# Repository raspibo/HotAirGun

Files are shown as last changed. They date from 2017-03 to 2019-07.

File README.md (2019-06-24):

HotAirGun
===================== 
Hot Air Solder station project
3D models for case

Project preview
=====================

<table>
<tr>
<td>
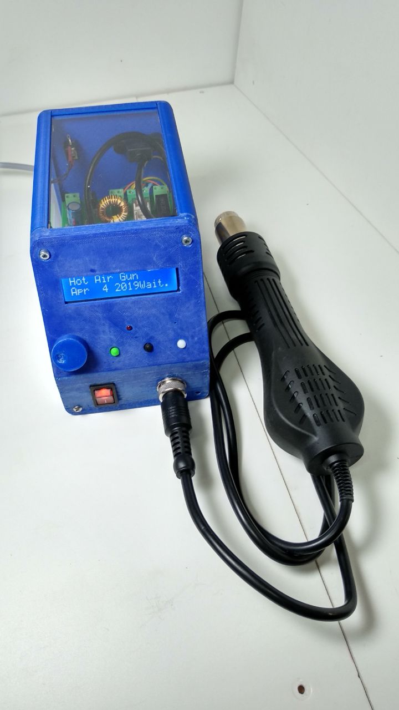
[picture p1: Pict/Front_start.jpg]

</td><td>
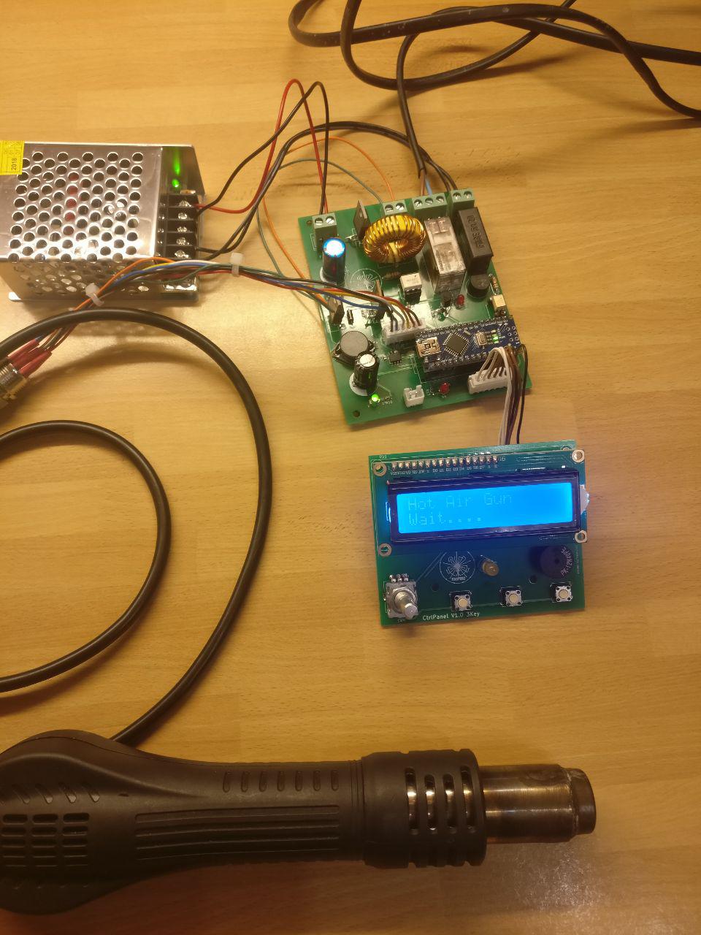
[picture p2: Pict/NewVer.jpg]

</td><td>
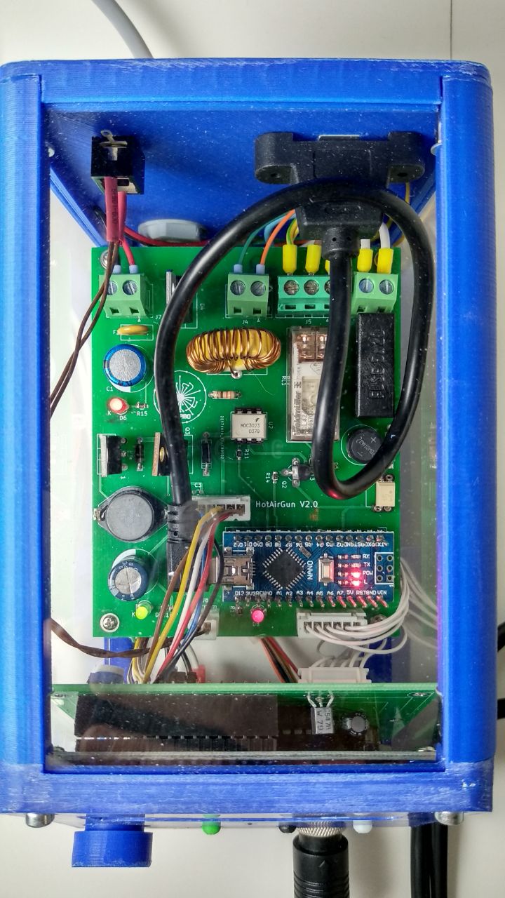
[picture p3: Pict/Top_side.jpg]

</td>
</tr>
<tr>
<td>
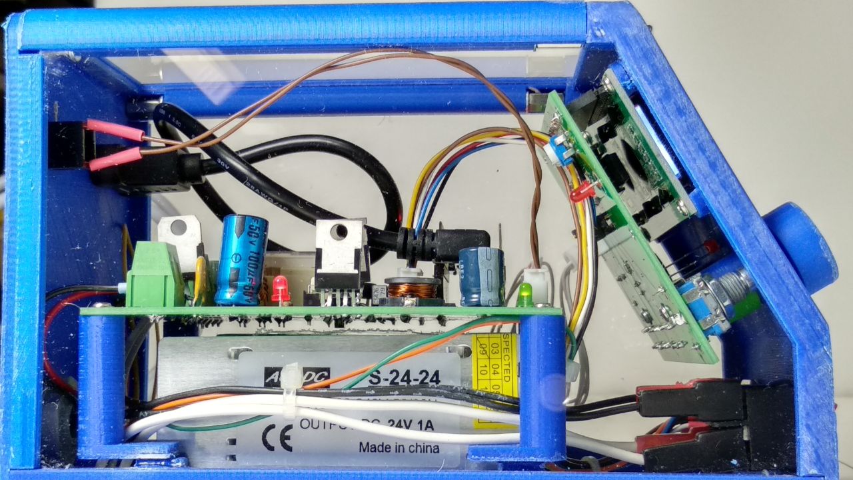
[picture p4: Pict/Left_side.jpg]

</td><td>
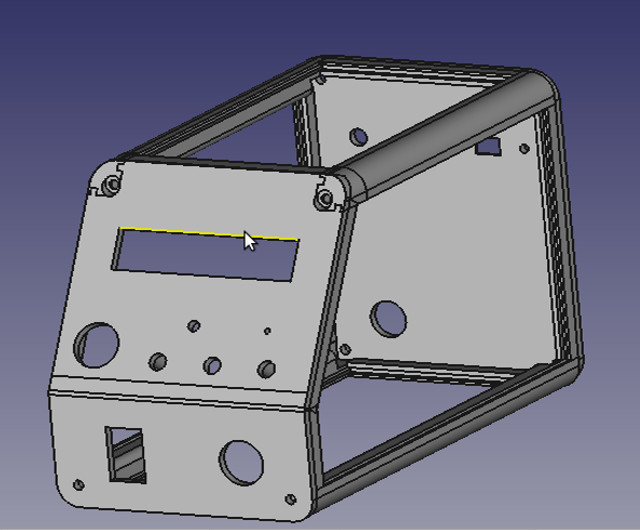
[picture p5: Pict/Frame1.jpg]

</td><td>
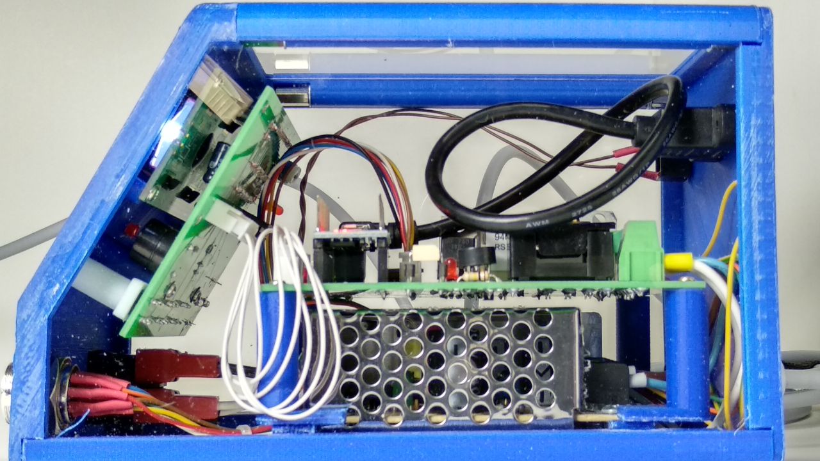
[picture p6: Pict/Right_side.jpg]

</td>
</tr>
</table>

License and copyright
=====================

Copyright 2017-2018 sandroxGH infomsystemsrl@gmail.com, RaspiBO info@raspibo.org

Licensed under the Apache License, Version 2.0 (the "License"); you may not use this file except in compliance with the License. You may obtain a copy of the License at http://www.apache.org/licenses/LICENSE-2.0

Unless required by applicable law or agreed to in writing, software distributed under the License is distributed on an "AS IS" BASIS, WITHOUT WARRANTIES OR CONDITIONS OF ANY KIND, either express or implied. See the License for the specific language governing permissions and limitations under the License.

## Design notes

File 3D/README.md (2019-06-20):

Mounting note for the HAG housing frame

===================== 

To build the frame I've use ABS more flexible and a good meccanical resistance than PLA, but finally all material are good. 
The model is slice at 0,15mm a good balnce between definistion and strenght.
For the column mounting have to add a threaded bar , 2 washer  and 2 spacer of 10mm all in M3 size. The upper column use e thread bar of 110mm and the lowe 158 mm, to asembly use threadlocker.

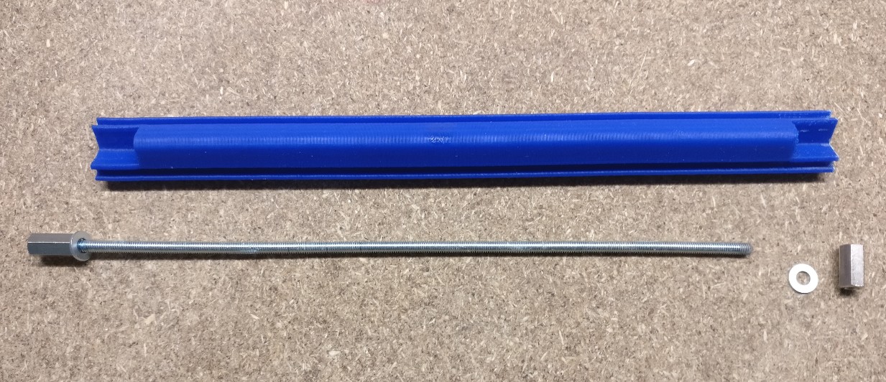
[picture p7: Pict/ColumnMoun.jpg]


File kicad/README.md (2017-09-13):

# Avvertenza sul caricamento dei simboli
All'apertura dello schema kicad può richiedere di sostituire i simboli dei componenti come se si riferissero a librerie obsolete.

E' consigliabile annullare l'operazione in modo che venga caricato il simbolo presente nel file cache delle librerie.

Schema preview
=====================


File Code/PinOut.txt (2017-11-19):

1	D1/TX	Connesisone seriale 
2	D0/RX	Connesisone seriale
3	RESET
4	GND
5	D2*		Fase 0
6	D3		MCP_INT
7	D4		
8	D5*		MAX6675_SO
9	D6* 	MAX6675_CS
10	D7		MAX6675_CLK
11	D8		Relè sic 220V
12	D9* 	Triac
13	D10*		
14	D11* 	Mosfet "Fan"
15	D12  	
16	D13		LedR
17	3V3		
18	AREF
19	A7		
20	A6		
21	A5		LCD I2c
22	A4		LCD I2c
23	A3		
24	A2		
25	A1		
26	A0		
27	+5V
28	RESET
29	GND
30	VIN

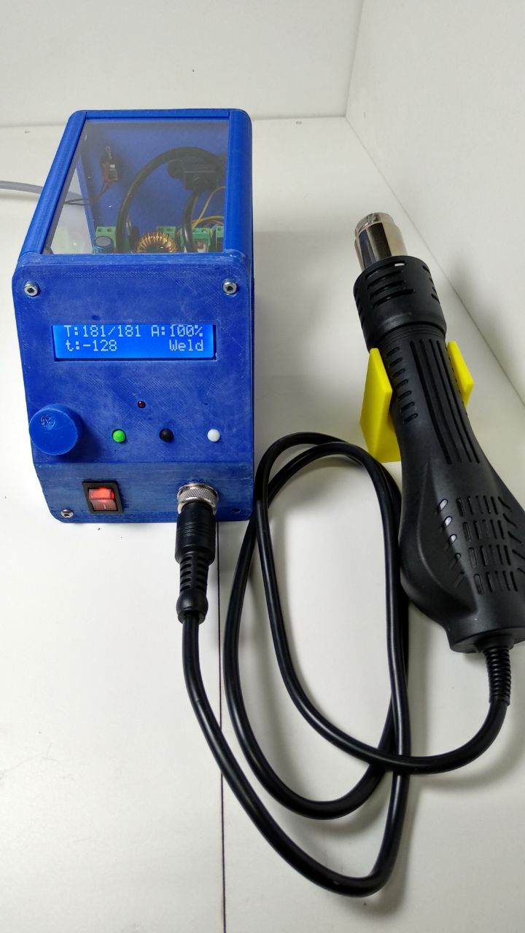
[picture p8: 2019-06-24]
Pict/Front_weld.jpg

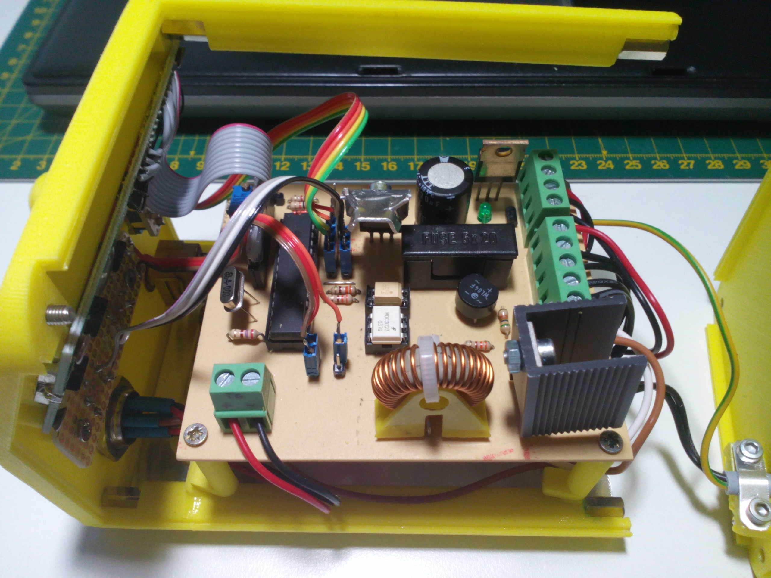
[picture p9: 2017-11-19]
Pict/HAG.jpg

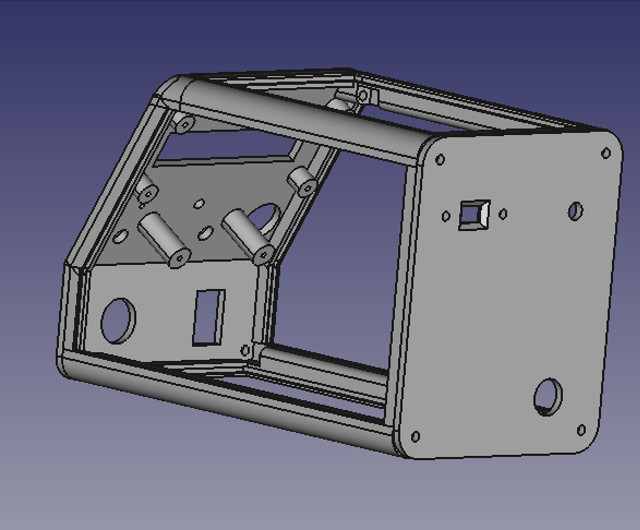
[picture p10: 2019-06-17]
Pict/Frame2.jpg

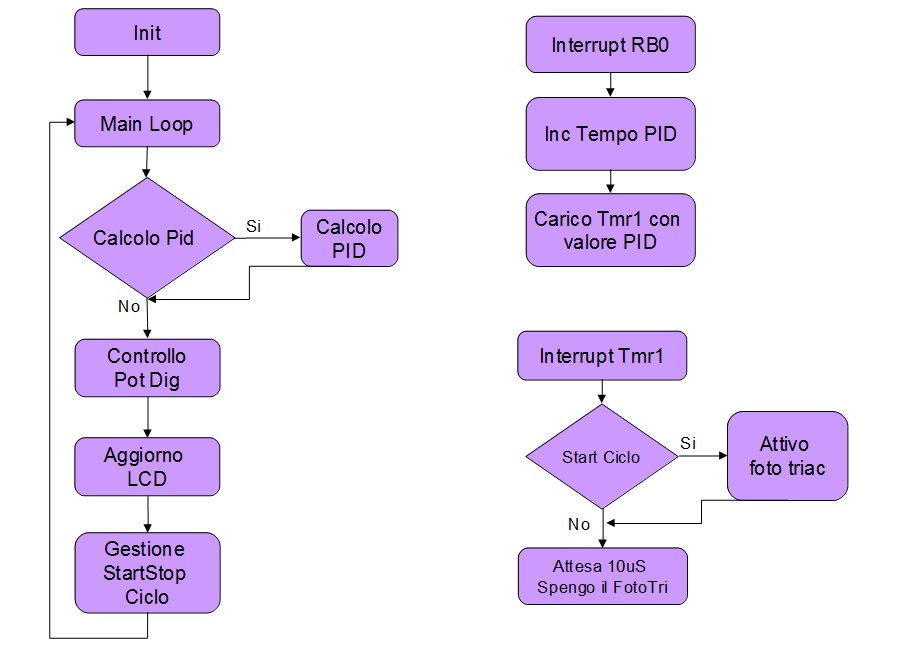
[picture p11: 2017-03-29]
Pict/Flow1.jpg

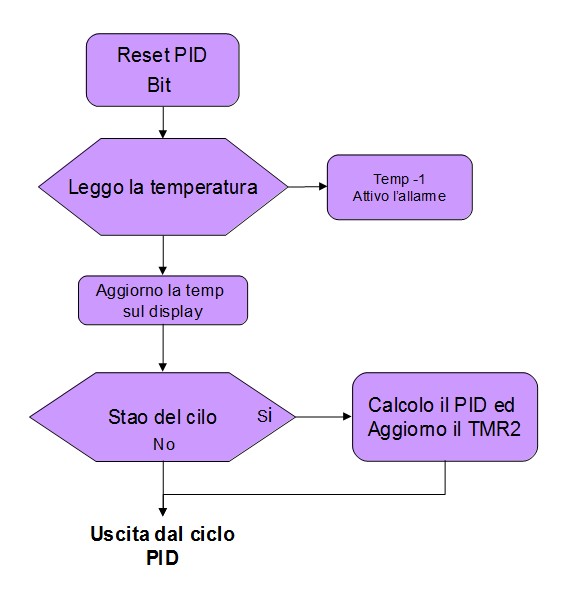
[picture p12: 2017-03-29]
Pict/Flow2.jpg

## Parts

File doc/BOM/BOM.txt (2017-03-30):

#Lista materiali per la sperimentazione iniziale

Quantita   Materiale
1          Pistola saldatore ad aria calda          
1          Arduino Nano
1          Display LCD 16x2
1          interfaccia per display I2c
1          Alimentatore switching 12V 2A    ( 24V 1A)
1          Encoder con click "Rotella multifunzione"
2          Pulsanti No
3          Led Verdi 3mm
1          Led Rosso 3mm
QB         Resistenze
1          MAX6675
1          IRF740
1          Porta fusibile 5x20
1          Ponte raddrizzatore
1          Fotocaccopiatore MOC3032
1          Fotocaccopiatore TLP672
1          Diodo BA159
1          Induttanza 10mH 1A
2          Condensatori ceramici 10pF

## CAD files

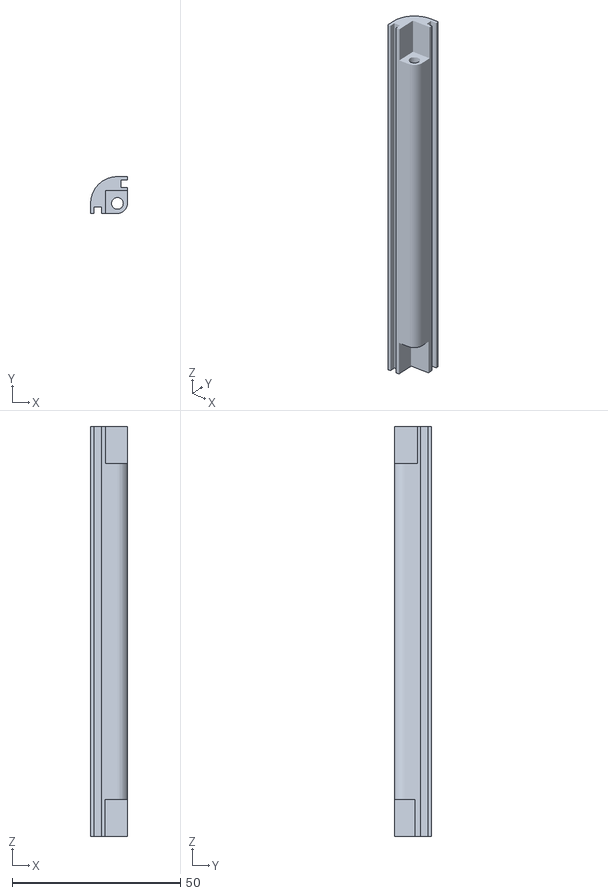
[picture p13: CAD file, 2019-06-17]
3D/Coloumn 123.stl
11.0 x 11.0 x 122.0

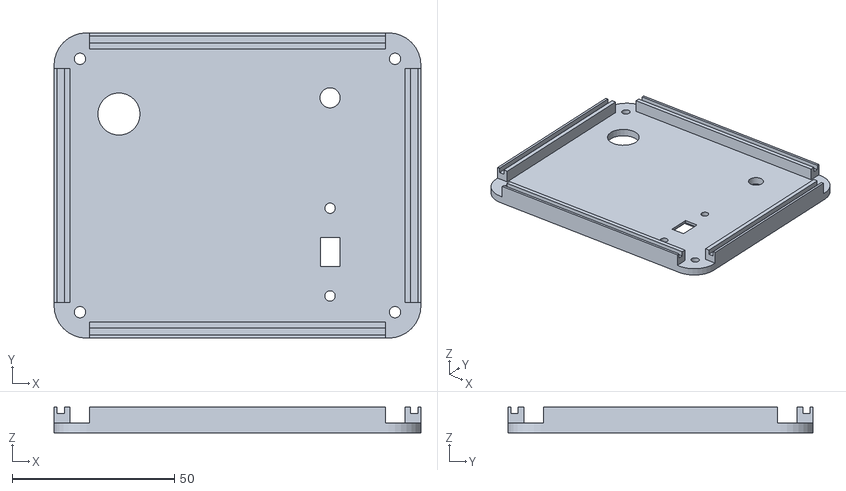
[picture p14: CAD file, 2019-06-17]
3D/Rear.stl
113.0 x 94.0 x 8.00

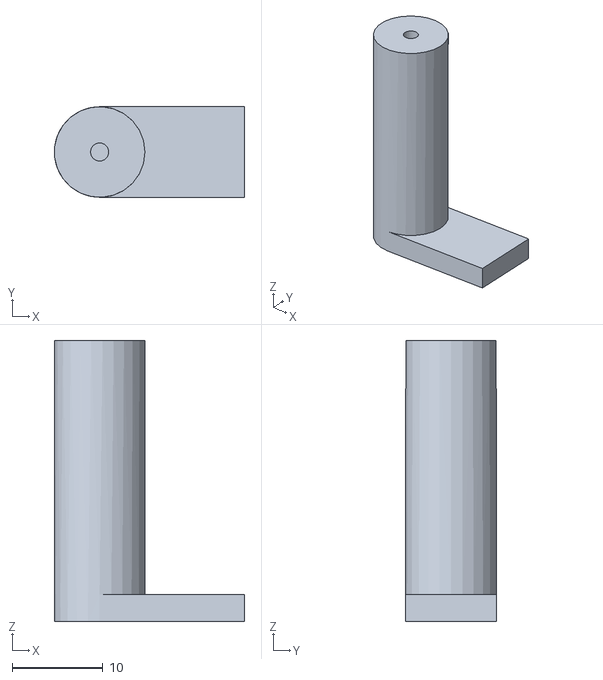
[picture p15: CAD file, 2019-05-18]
3D/Pcb Fixing.stl
21.0 x 10.0 x 31.0

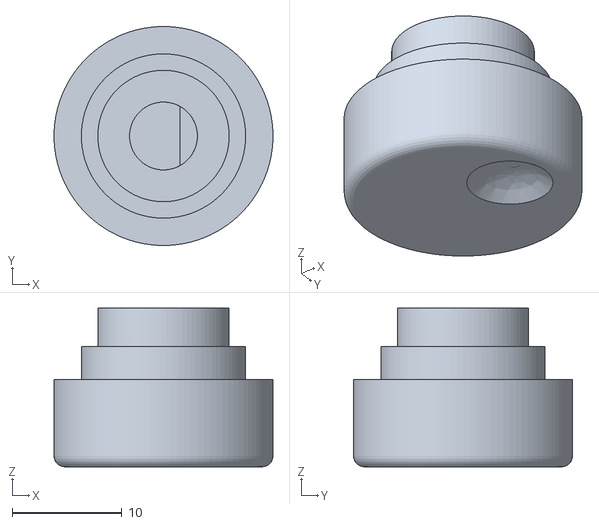
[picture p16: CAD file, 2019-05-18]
3D/Pot.stl
20.0 x 20.0 x 14.5

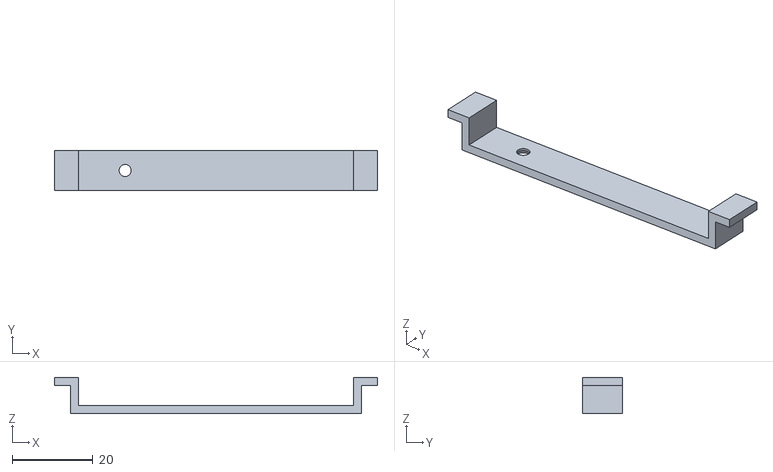
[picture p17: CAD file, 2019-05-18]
3D/P-S Fixing.stl
80.0 x 10.0 x 9.00

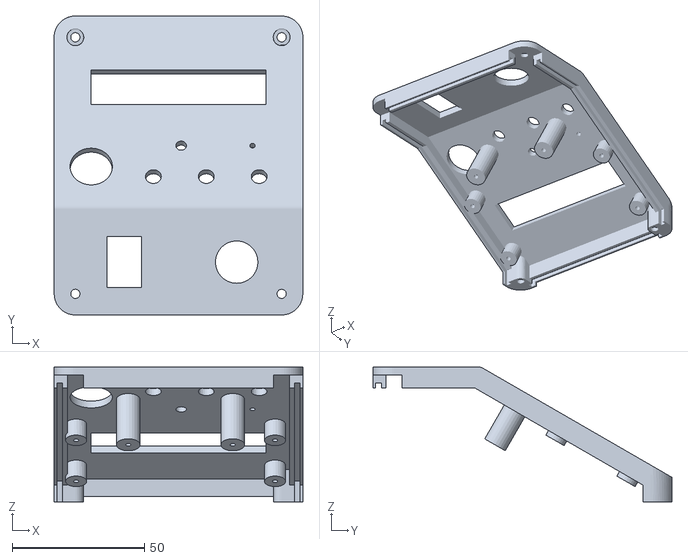
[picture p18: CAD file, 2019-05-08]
3D/Front.stl
94.0 x 113.1 x 51.0

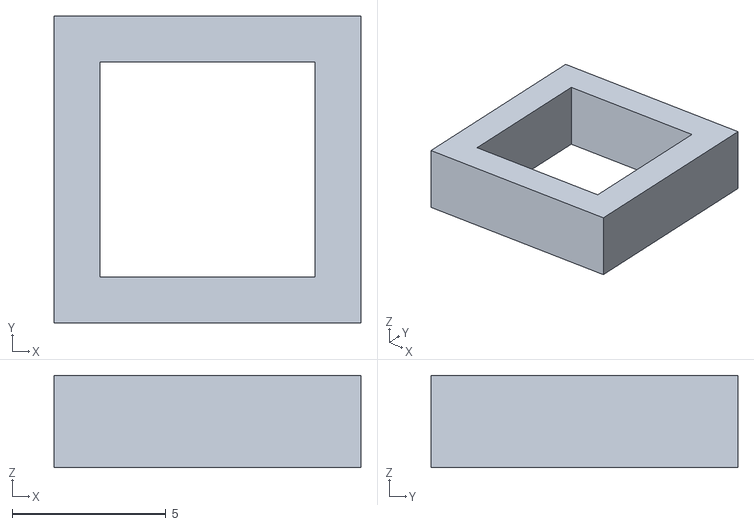
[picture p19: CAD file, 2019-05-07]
3D/Button.stl
10.0 x 10.0 x 3.00

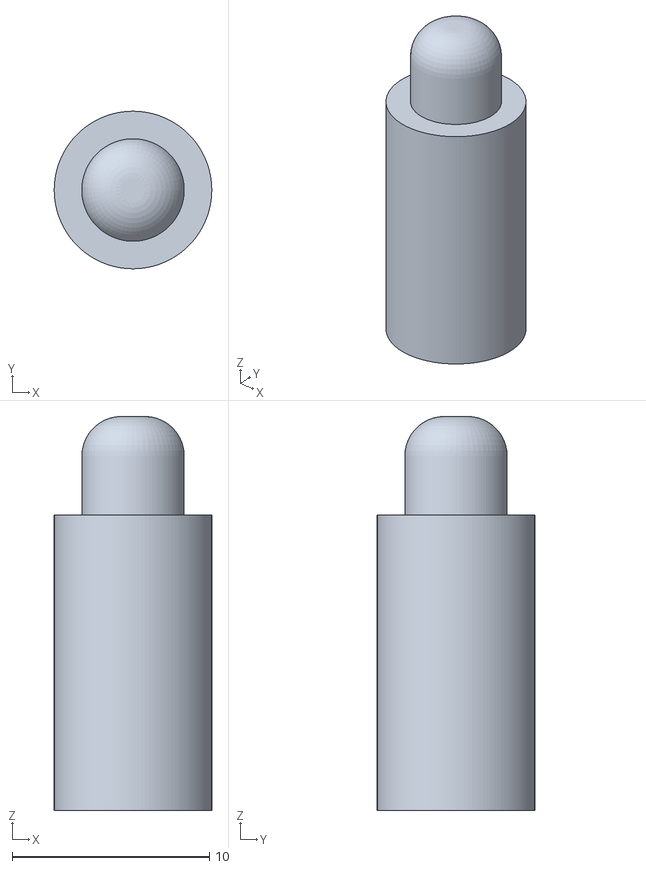
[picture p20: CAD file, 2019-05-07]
3D/Button1.stl
8.00 x 8.00 x 20.0

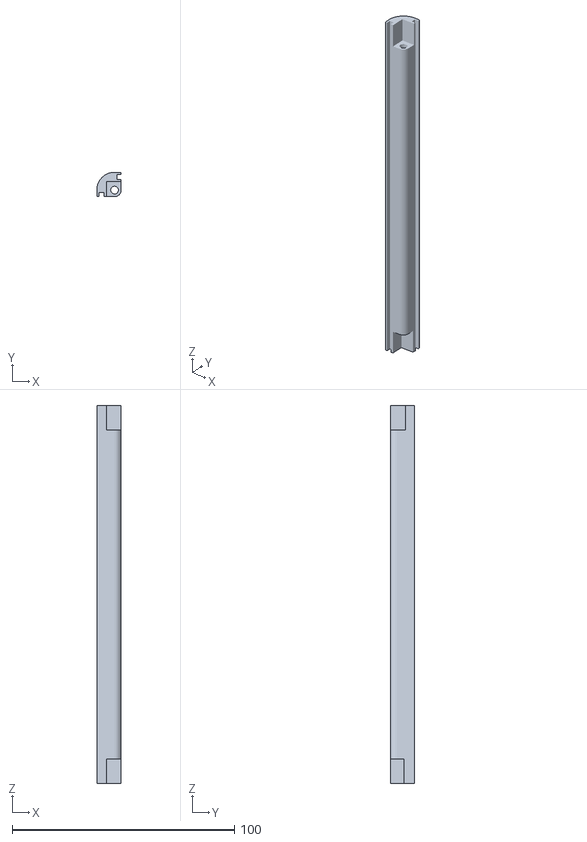
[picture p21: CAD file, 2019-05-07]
3D/Coloumn 170.stl
11.0 x 11.0 x 170.0

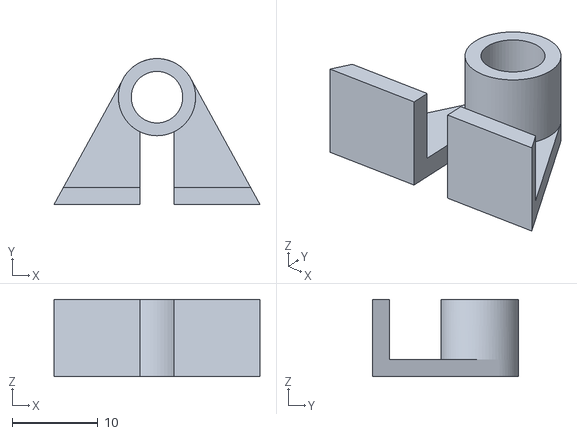
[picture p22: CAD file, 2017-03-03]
3D/CoilSupport.stl
24.0 x 17.0 x 9.00

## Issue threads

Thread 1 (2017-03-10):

Visualizzazione dati su pc

dcast78, 2017-03-10:
Rispetto alle stazioni ad aria calda anche commerciali, il progetto potrebbe diventare ancora piu' interessante se fosse possibile leggere i dati di qualche variabile su connessione seriale.

Servirebbe per esempio stampare i valori di temperatura visualizzati su display per poter disegnare un grafico su pc.

Questo renderebbe piu' chiaro anche comprendere il funzionamento dell'algoritmo PID disegnando un grafico su pc

Closed 2019-02-19.

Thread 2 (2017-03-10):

Implementare una funzione di sicurezza per consentire l'uso a temperature non pericolose.

dcast78, 2017-03-10:
Visto che nel nostro gruppo ci sono anche piccoli makers.

Sarebbe utile poter limitare la temperatura massima in uscita dalla stazione a temperature non pericolose.

La stazione in questo caso sarebbe utilizzabile da chiunque per esempio per seccare venici senza correre il pericolo di scottarsi.

Si potrebbe prevedere una modalita' safe per l basse temperature ed una solder per le alte tramite l'uso di una "password" senza necessariamente dover ricaricare il firmware per passare da una modalita' all'altra.

Closed 2019-02-19.

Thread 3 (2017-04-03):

Implementare una funzione di auto spegnimento

dcast78, 2017-04-03:
Per evitare consumi inutili e incidenti è utile prevedere una funzione di auto spegnimento della stazione per inutilizzo.
E' utile che dopo un periodo di qualche ora (magari impostabile) la stazione si spenga automaticamente per evitare consumi ed incendi..

Closed 2019-02-19.

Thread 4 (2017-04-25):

Creare impostazioni predefinite per materiali diversi

dcast78, 2017-04-25:
Per la saldatura di materiali plastici sarebbe utile memorizzare temperature selezionabili direttamente da menù. Es polipropilene 205 °C velocità ventola bassa.

Closed 2019-02-19.

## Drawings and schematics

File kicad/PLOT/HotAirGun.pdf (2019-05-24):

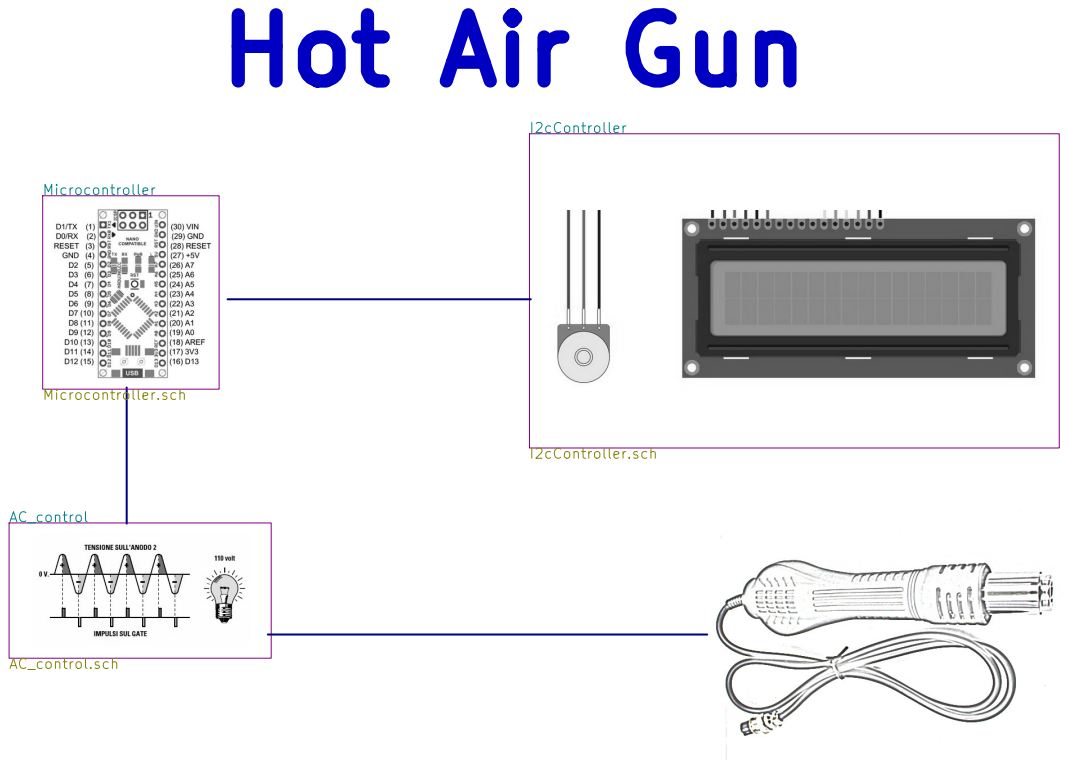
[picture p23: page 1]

http://www.raspibo.org/wiki/index.php?title=HotAirGun
Copyright 2017-2018 sandroxGH infomsystemsrl@gmail.com, RaspiBO info@raspibo.org
Licensed under the Apache License, Version 2.0 (the "License")
You may obtain a copy of the License at http://www.apache.org/licenses/LICENSE-2.0
File: HotAirGun.sch Sheet: / Raspibo

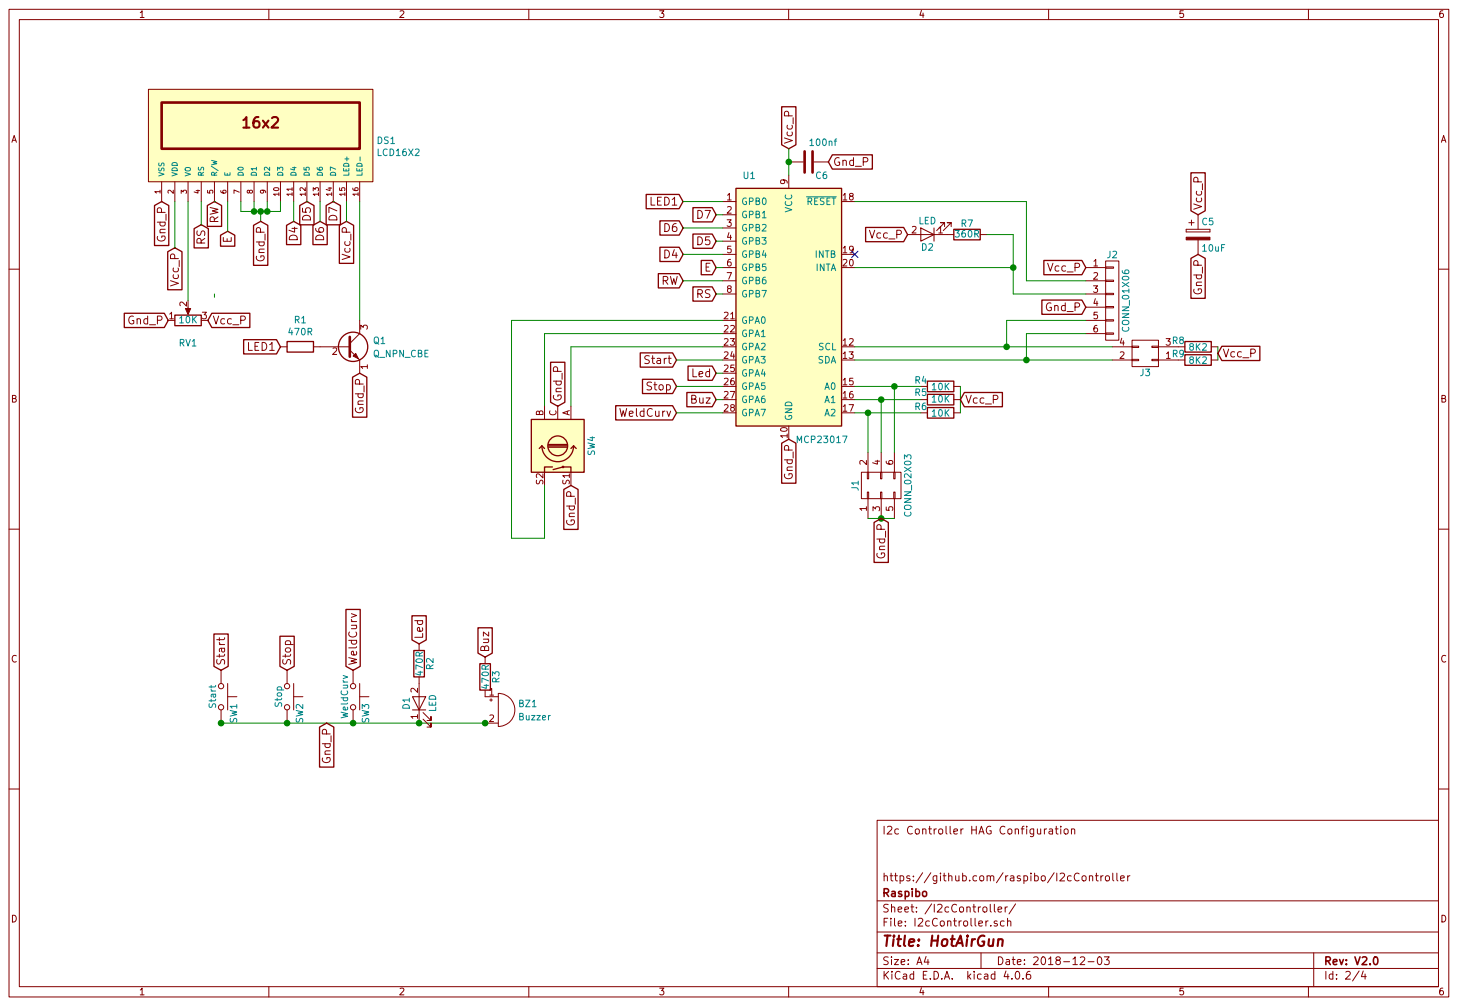
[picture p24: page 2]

https://github.com/raspibo/I2cController
File: I2cController.sch Sheet: /I2cController/ Raspibo

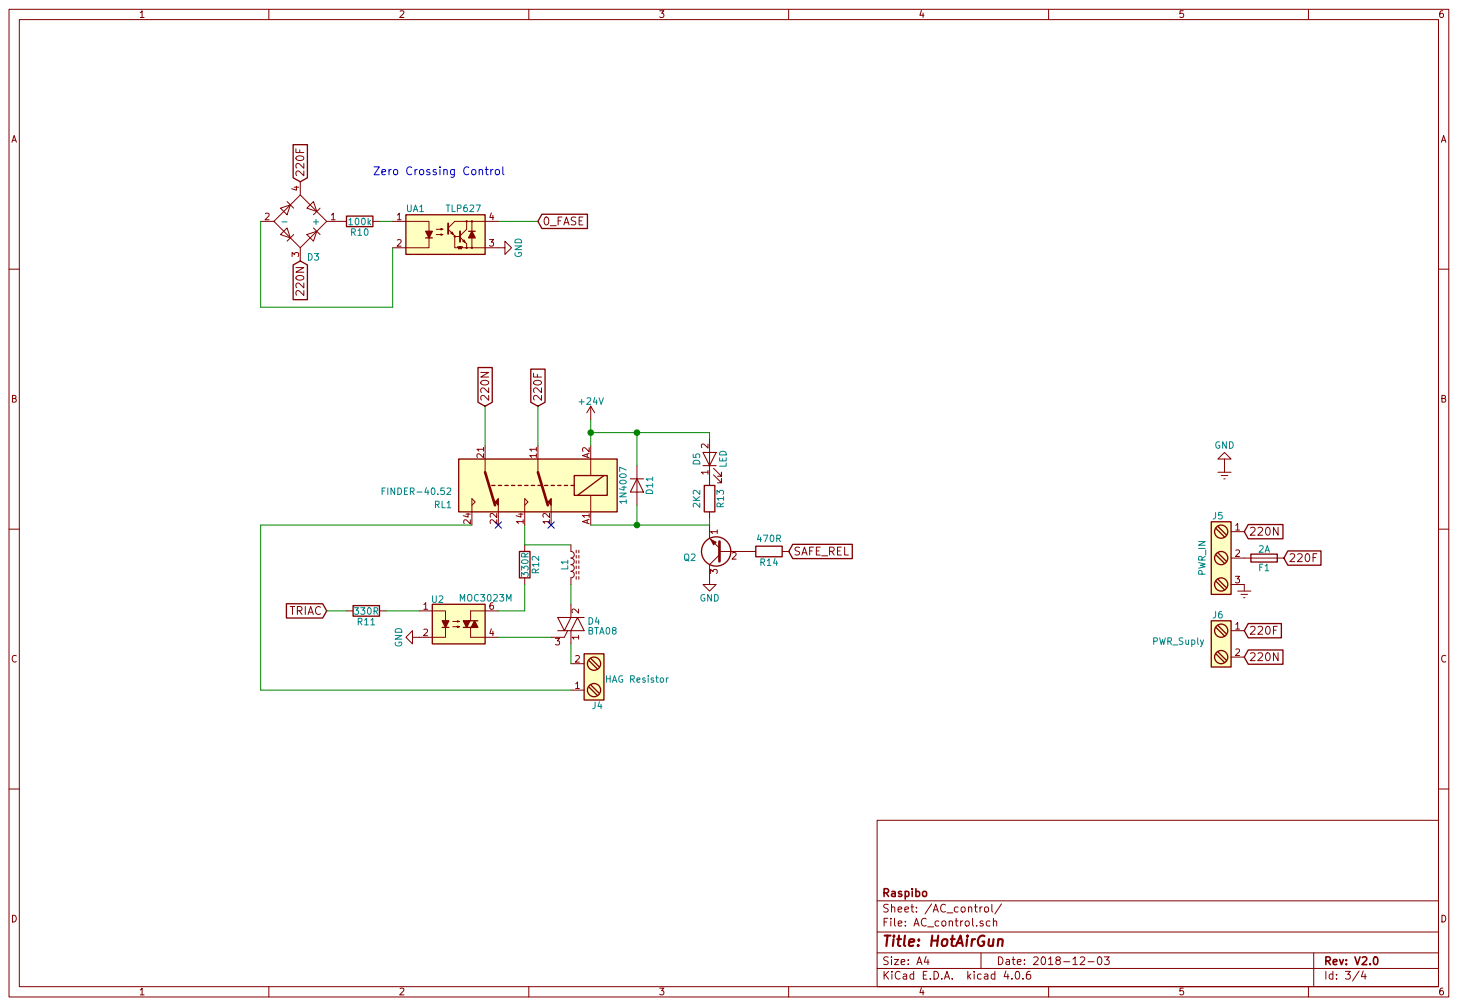
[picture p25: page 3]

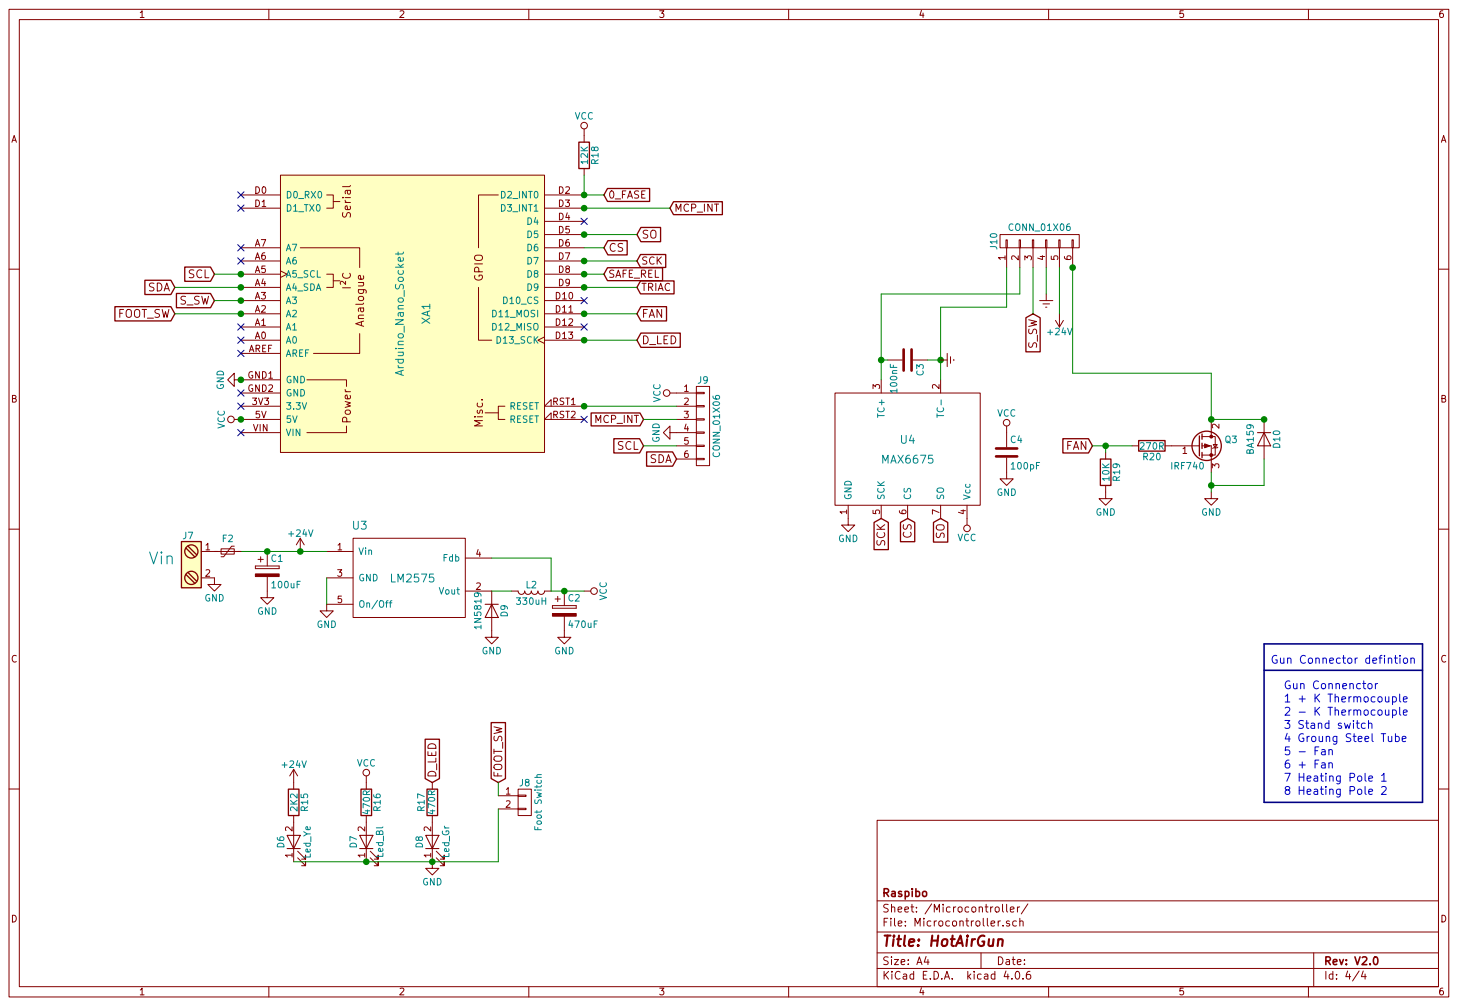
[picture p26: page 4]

File: Microcontroller.sch Sheet: /Microcontroller/ Raspibo

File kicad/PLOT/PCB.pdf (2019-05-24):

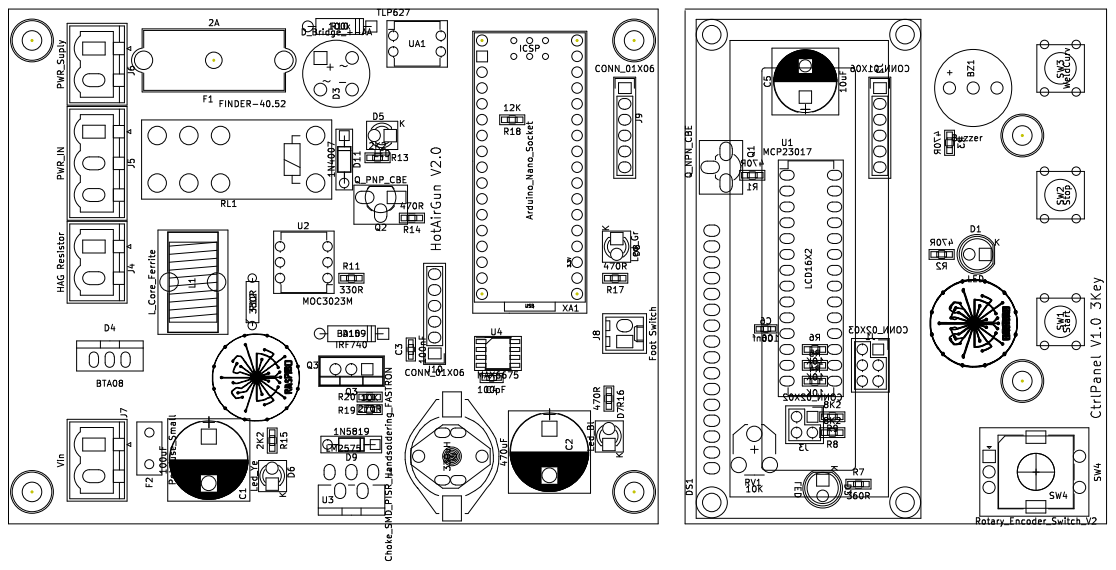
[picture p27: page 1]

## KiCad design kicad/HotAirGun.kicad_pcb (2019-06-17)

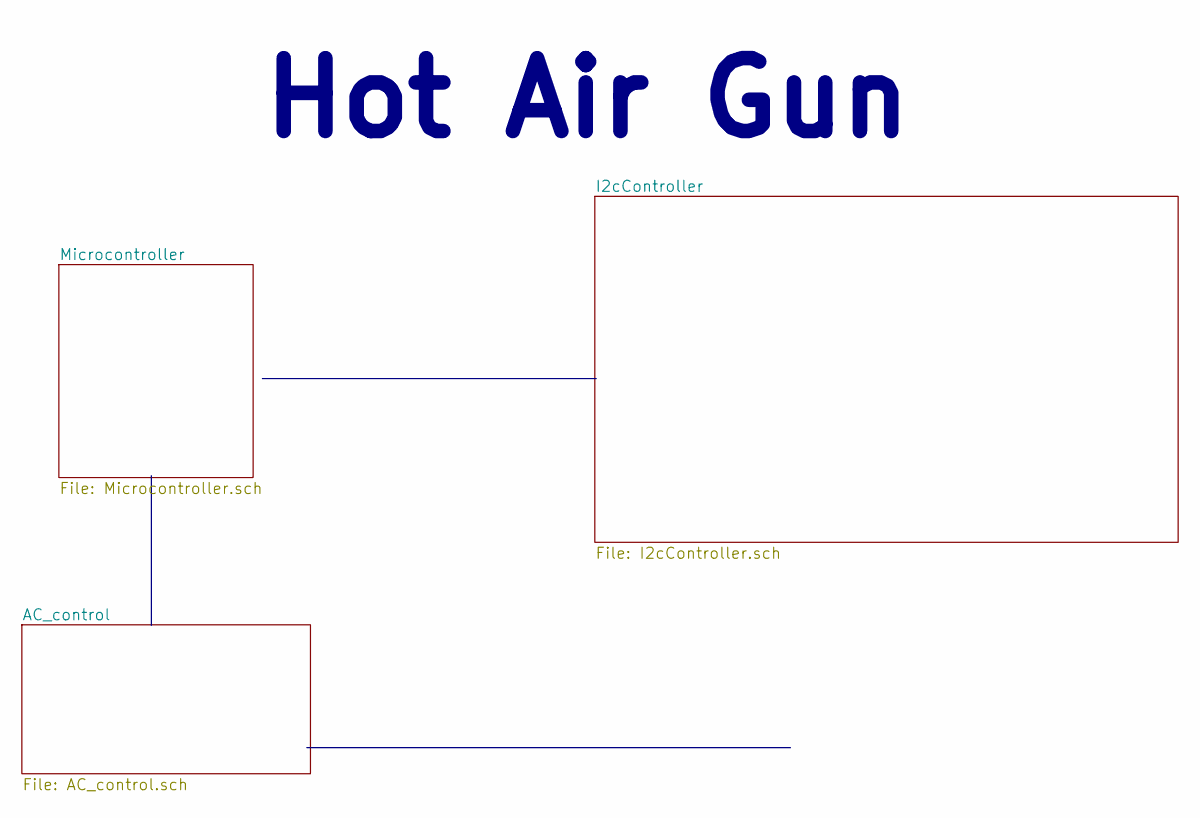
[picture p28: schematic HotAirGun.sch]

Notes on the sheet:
Hot Air Gun

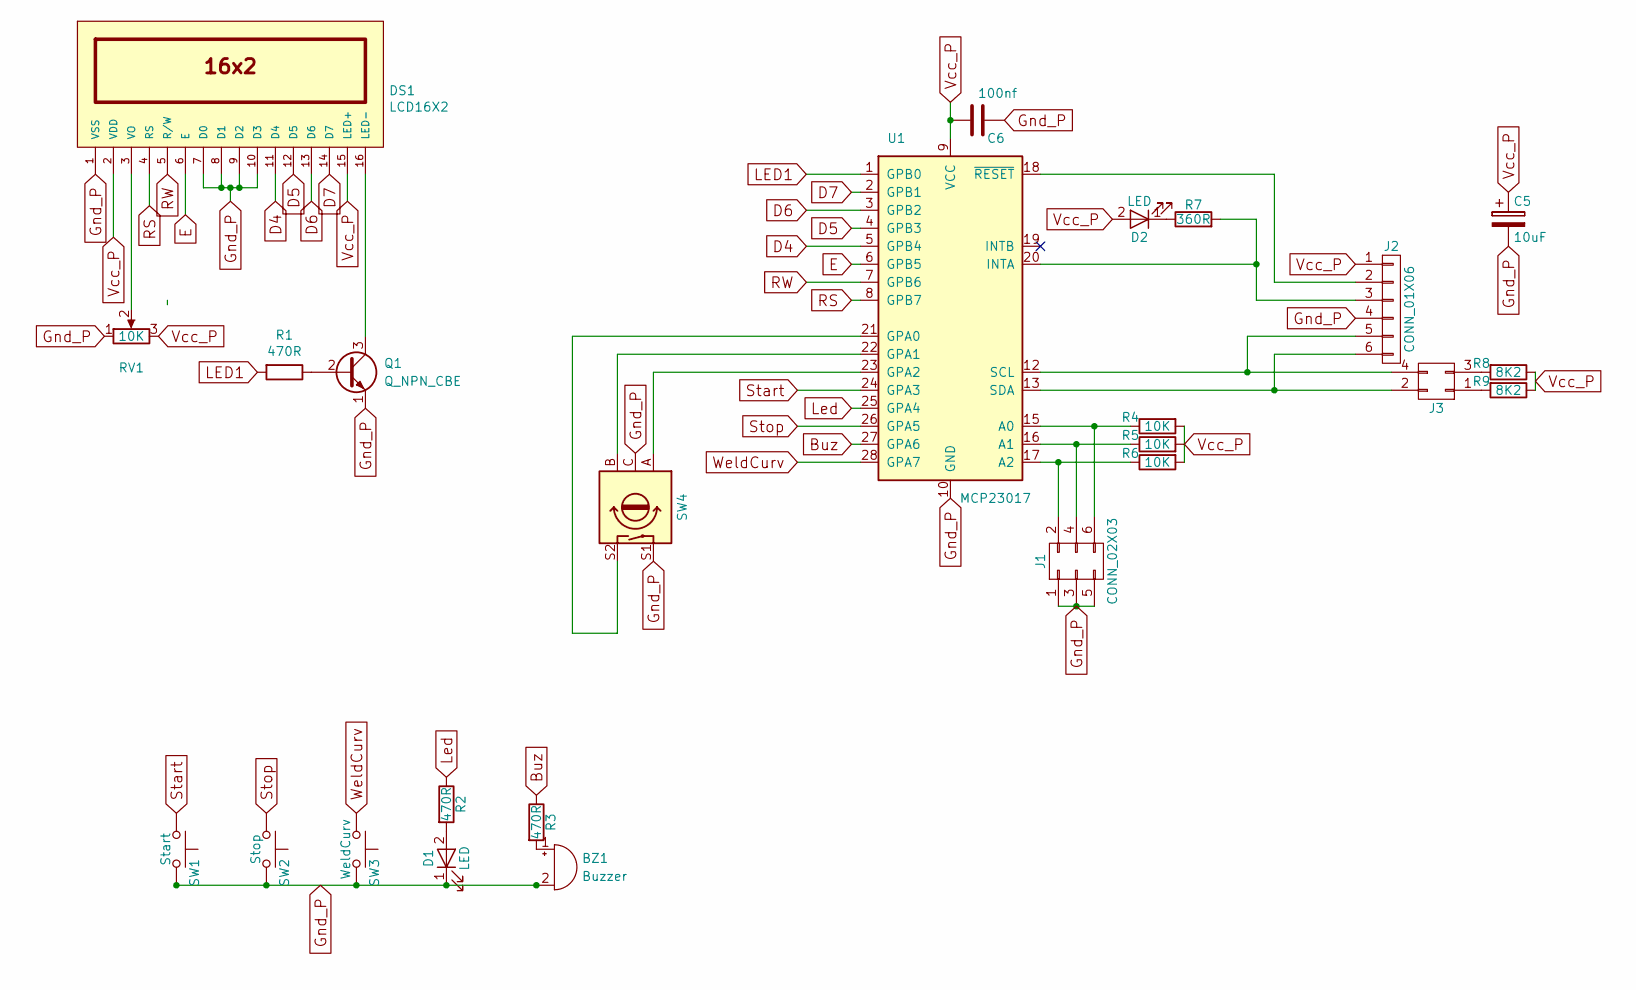
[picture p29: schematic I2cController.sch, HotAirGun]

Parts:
BZ1: Buzzer; Buzzer_12x9.5RM7.6
C5: 10uF; CP_Radial_D10.0mm_P5.00mm
C6: 100nf; C_0603_HandSoldering
D1, D2: LED; LED-5MM
DS1: LCD16X2; WC1602A
J1: CONN_02X03; Pin_Header_Straight_2x03
J2: CONN_01X06; Pin_Header_Straight_1x06
J3: CONN_02X02; Pin_Header_Straight_2x02
Q1: Q_NPN_CBE; TO-92_Rugged_Reverse
R1: 470R; R3
R2, R3: 470R; R_0603_HandSoldering
R4, R5, R6: 10K; R_0603_HandSoldering
R7: 360R; R_0603_HandSoldering
R8, R9: 8K2; R_0603_HandSoldering
RV1: 10K; Potentiometer_VishaySpectrol-Econtrim-Type36M
SW1: Start; SW_PUSH_SMALL
SW2: Stop; SW_PUSH_SMALL
SW3: WeldCurv; SW_PUSH_SMALL
SW4: Rotary_Encoder_Switch_V2; RotaryEncoder_Alps_EC11E-Switch_Vertical_H20mm
U1: MCP23017; DIP-28_W7.62mm_LongPads

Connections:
Buz: R3.1, U1.27 (GPA6)
D4: DS1.11 (D4), U1.5 (GPB4)
D5: DS1.12 (D5), U1.4 (GPB3)
D6: DS1.13 (D6), U1.3 (GPB2)
D7: DS1.14 (D7), U1.2 (GPB1)
E: DS1.6 (E), U1.6 (GPB5)
Gnd_P: BZ1.2 (+), C5.2, C6.1, D1.1 (K), DS1.1 (VSS), DS1.7 (D0), DS1.8 (D1), DS1.9 (D2), DS1.10 (D3), J1.1, J1.3, J1.5, J2.4, Q1.1 (E), RV1.1, SW1.2, SW2.2, SW3.2, SW4.C, SW4.S1, U1.10 (GND)
LED1: R1.2, U1.1 (GPB0)
Led: R2.1, U1.25 (GPA4)
unnamed: BZ1.1 (-), R3.2
unnamed: D1.2 (A), R2.2
unnamed: D2.1 (K), R7.1
unnamed: DS1.3 (VO), RV1.2
unnamed: DS1.16 (LED-), Q1.3 (C)
unnamed: J1.2, R6.1, U1.17 (A2)
unnamed: J1.4, R5.1, U1.16 (A1)
unnamed: J1.6, R4.1, U1.15 (A0)
unnamed: J2.2, U1.18 (~RESET)
unnamed: J2.3, R7.2, U1.20 (INTA)
unnamed: J2.5, J3.4, U1.12 (SCL)
unnamed: J2.6, J3.2, U1.13 (SDA)
unnamed: J3.1, R9.2
unnamed: J3.3, R8.2
unnamed: Q1.2 (B), R1.1
unnamed: SW4.A, U1.23 (GPA2)
unnamed: SW4.B, U1.22 (GPA1)
unnamed: SW4.S2, U1.21 (GPA0)
RS: DS1.4 (RS), U1.8 (GPB7)
RW: DS1.5 (R/W), U1.7 (GPB6)
Start: SW1.1, U1.24 (GPA3)
Stop: SW2.1, U1.26 (GPA5)
Vcc_P: C5.1, C6.2, D2.2 (A), DS1.2 (VDD), DS1.15 (LED+), J2.1, R4.2, R5.2, R6.2, R8.1, R9.1, RV1.3, U1.9 (VCC)
WeldCurv: SW3.1, U1.28 (GPA7)

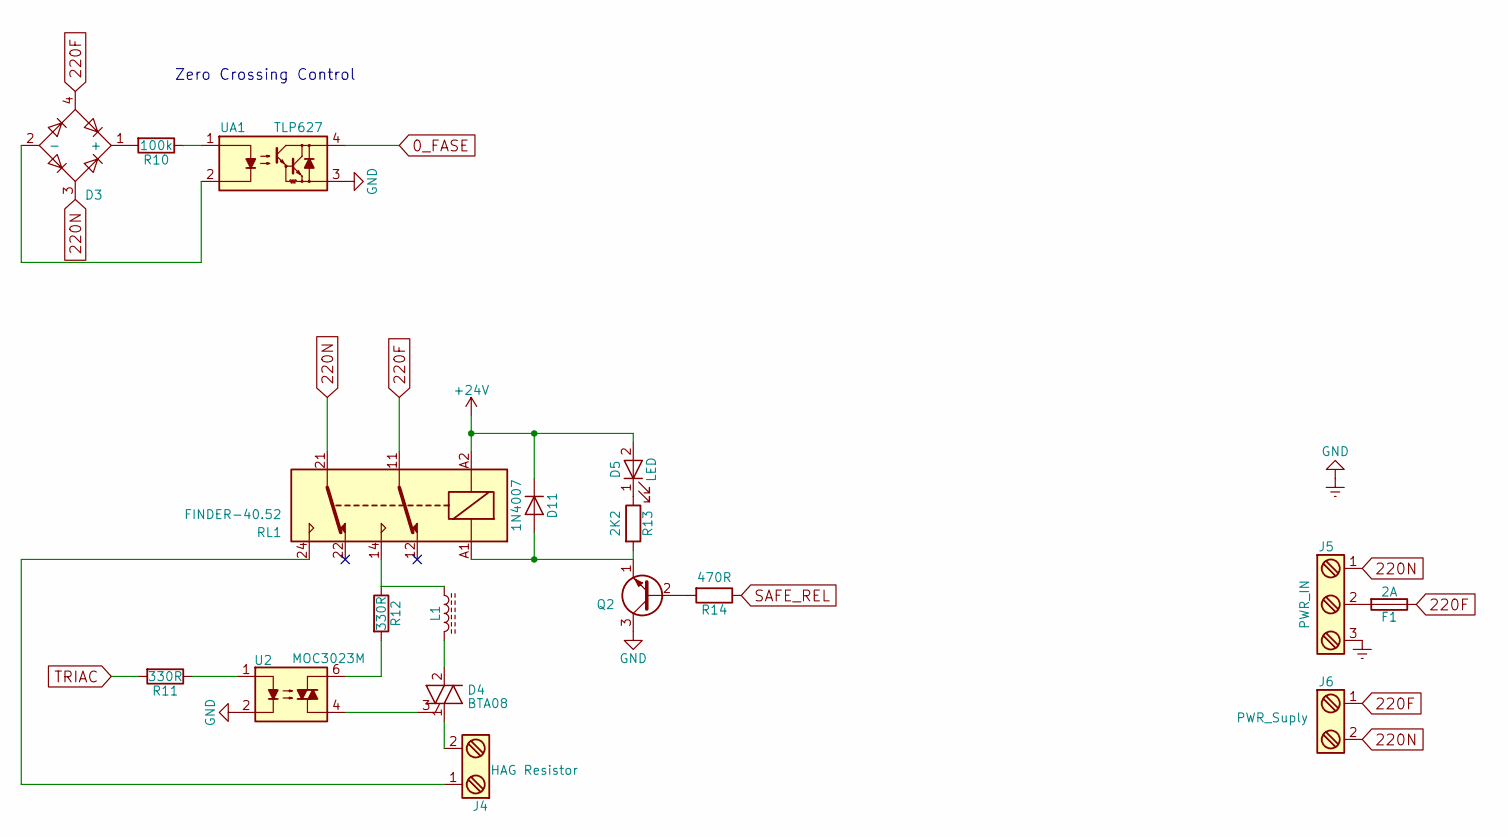
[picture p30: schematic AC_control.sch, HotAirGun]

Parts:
D3: D_Bridge_+-AA; Diode_Bridge_8.5
D4: BTA08; TO-220_Neutral123_Vertical
D5: LED; LED-3MM
D11: 1N4007; D_DO-35_SOD27_P7.62mm_Horizontal
F1: 2A; Fuseholder5x20_horiz_open_Schurter_0031_8201
J4: HAG Resistor; PhoenixContact_MSTBVA-G_02x5.08mm_Vertical
J5: PWR_IN; PhoenixContact_MSTBVA-G_03x5.08mm_Vertical
J6: PWR_Suply; PhoenixContact_MSTBVA-G_02x5.08mm_Vertical
L1: L_Core_Ferrite; Choke_SMD_PISR_Handsoldering_FASTRON
Q2: Q_PNP_CBE; TO-92_Rugged
R10: 100k; D4
R11: 330R; Resistor_Horizontal_RM7mm
R12: 330R; R3
R13: 2K2; R_0603_HandSoldering
R14: 470R; R_0603_HandSoldering
RL1: FINDER-40.52; Relay_SPDT_Schrack-RT1_RM5mm
U2: MOC3023M; DIP-6_W7.62mm
UA1: TLP627; DIP-4_W7.62mm

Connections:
0_FASE: UA1.4; also elsewhere on the board
220F: D3.4, F1.1, J6.1, RL1.11
220N: D3.3, J5.1, J6.2, RL1.21
+24V: D5.2 (A), D11.1 (K), RL1.A2; also elsewhere on the board
Earth: J5.3, Q2.3 (C), U2.2, UA1.3; also elsewhere on the board
unnamed: D3.1 (+), R10.2
unnamed: D3.2 (-), UA1.2
unnamed: D4.1 (A1), J4.2
unnamed: D4.2 (A2), L1.2
unnamed: D4.3 (G), U2.4
unnamed: D5.1 (K), R13.1
unnamed: D11.2 (A), Q2.1 (E), R13.2, RL1.A1
unnamed: F1.2, J5.2
unnamed: J4.1, RL1.24
unnamed: L1.1, R12.1, RL1.14
unnamed: Q2.2 (B), R14.2
unnamed: R10.1, UA1.1
unnamed: R11.1, U2.1
unnamed: R12.2, U2.6
SAFE_REL: R14.1; also elsewhere on the board
TRIAC: R11.2; also elsewhere on the board

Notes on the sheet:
Zero Crossing Control

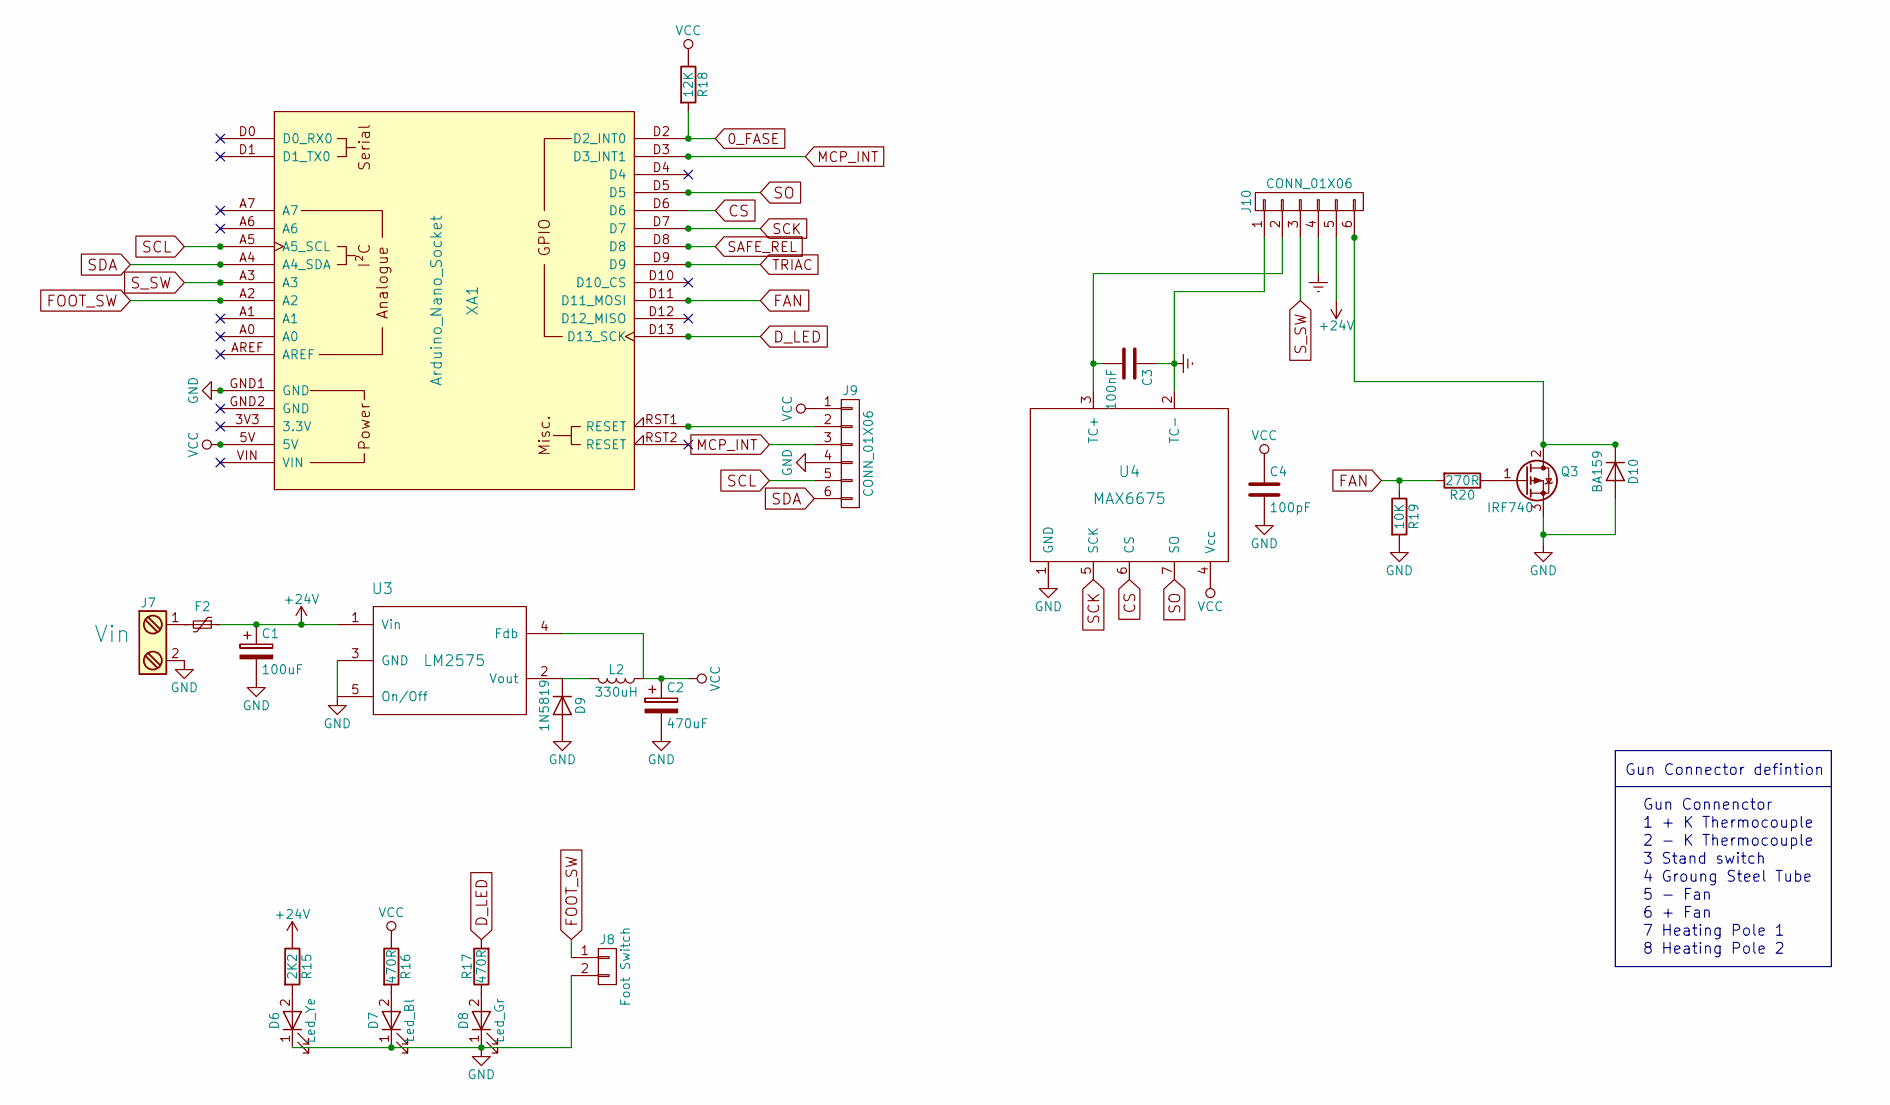
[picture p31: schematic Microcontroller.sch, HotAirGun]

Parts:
C1: 100uF; CP_Radial_D12.5mm_P7.50mm
C2: 470uF; CP_Radial_D12.5mm_P7.50mm
C3: 100nF; C_0603_HandSoldering
C4: 100pF; C_0603_HandSoldering
D6: Led_Ye; LED-3MM
D7: Led_Bl; LED-3MM
D8: Led_Gr; LED-3MM
D9: 1N5819; D_DO-35_SOD27_P7.62mm_Horizontal
D10: BA159; D4
F2: Polyfuse_Small; Fuseholder5x20_horiz_open_Schurter_0031_8201
J7: Vin; PhoenixContact_MSTBVA-G_02x5.08mm_Vertical
J8: Foot Switch; JACK_ALIM
J9, J10: CONN_01X06; Pin_Header_Straight_1x06
L2: 330uH; Induttanza
Q3: IRF740; TO-220_Vertical
R15: 2K2; R_0603_HandSoldering
R16, R17: 470R; R_0603_HandSoldering
R18: 12K; R_0603_HandSoldering
R19: 10K; R_0603_HandSoldering
R20: 270R; R_0603_HandSoldering
U3: LM2575; Pentawatt_Neutral_Staggered_Verical_TO220-5-T05D
U4: MAX6675; SOIC-8_3.9x4.9mm_Pitch1.27mm
XA1: Arduino_Nano_Socket

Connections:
0_FASE: R18.2, XA1.D2 (D2_INT0); also elsewhere on the board
+24V: C1.1, F2.1, J10.5, R15.1, U3.1 (Vin); also elsewhere on the board
CS: U4.6 (CS), XA1.D6
D_LED: R17.2, XA1.D13 (D13_SCK)
Earth: C1.2, C2.2, C3.1, C4.2, D6.1 (K), D7.1 (K), D8.1 (K), D9.2 (A), D10.2 (A), J7.2, J8.2, J9.4, J10.1, J10.4, Q3.3 (S), R19.2, U3.3 (GND), U3.5 (On/Off), U4.1 (GND), U4.2 (TC-), XA1.GND1 (GND); also elsewhere on the board
FAN: R19.1, R20.2, XA1.D11 (D11_MOSI)
FOOT_SW: J8.1, XA1.A2
MCP_INT: J9.3, XA1.D3 (D3_INT1)
unnamed: C3.2, J10.2, U4.3 (TC+)
unnamed: D6.2 (A), R15.2
unnamed: D7.2 (A), R16.2
unnamed: D8.2 (A), R17.1
unnamed: D9.1 (K), L2.2, U3.2 (Vout)
unnamed: D10.1 (K), J10.6, Q3.2 (D)
unnamed: F2.2, J7.1
unnamed: J9.2, XA1.RST1 (RESET)
unnamed: Q3.1 (G), R20.1
SAFE_REL: XA1.D8; also elsewhere on the board
SCK: U4.5 (SCK), XA1.D7
SCL: J9.5, XA1.A5 (A5_SCL)
SDA: J9.6, XA1.A4 (A4_SDA)
SO: U4.7 (SO), XA1.D5
S_SW: J10.3, XA1.A3
TRIAC: XA1.D9; also elsewhere on the board
VCC: C2.1, C4.1, J9.1, L2.1, R16.1, R18.1, U3.4 (Fdb), U4.4 (Vcc), XA1.5V

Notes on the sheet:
Gun Connenctor
1 + K Thermocouple
2 - K Thermocouple
3 Stand switch
4 Groung Steel Tube
5 - Fan
6 + Fan
7 Heating Pole 1
8 Heating Pole 2
Gun Connector defintion

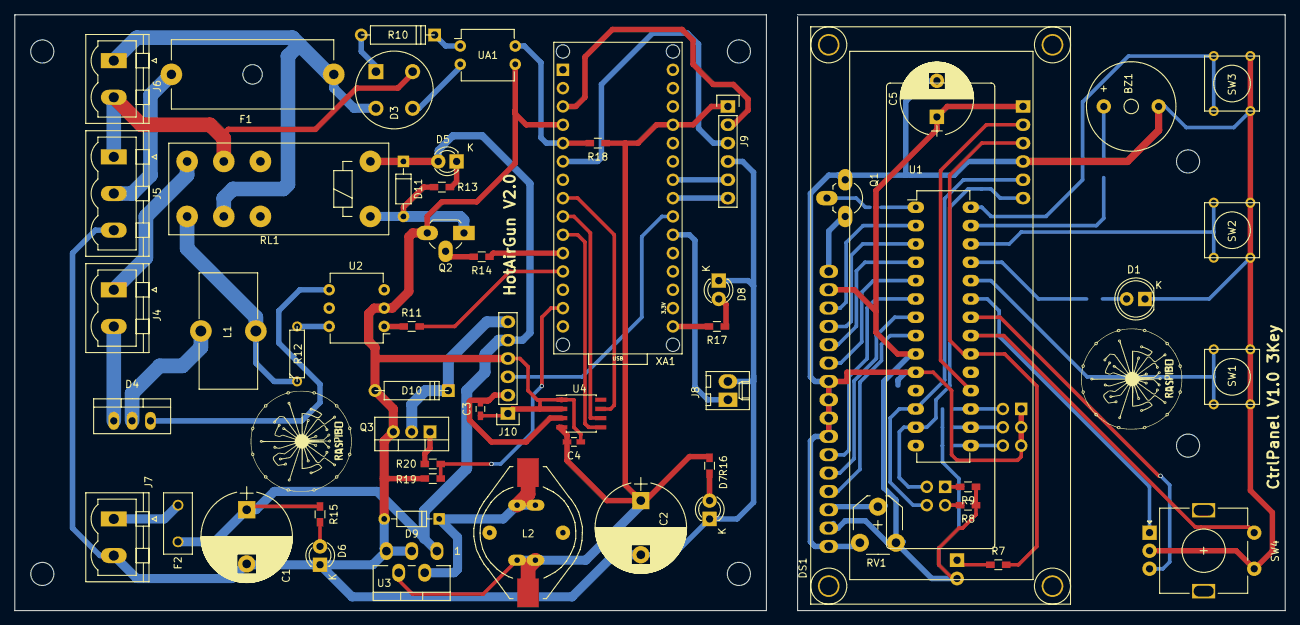
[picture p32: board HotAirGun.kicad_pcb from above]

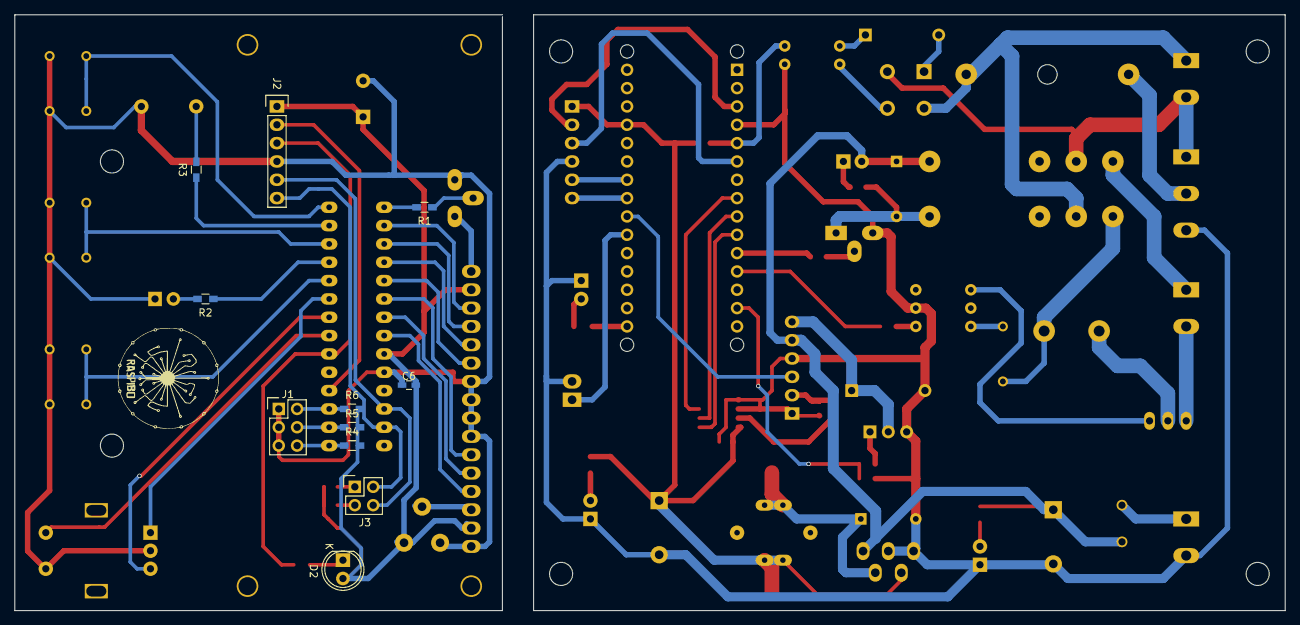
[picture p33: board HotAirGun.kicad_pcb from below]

Board: 2 copper layers, 176.0 x 82.5 mm, 68 parts (11 on the bottom side), 74 nets.

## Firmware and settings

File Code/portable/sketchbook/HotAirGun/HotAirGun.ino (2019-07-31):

//Code and project description http://www.raspibo.org/wiki/index.php?title=HotAirGun

// include the library code:
#include <Wire.h>
#include <CtrlPanel.h>
#include <EEPROM.h>

//Debug
#define SerialPlot
//#define F_Debug			//Uncomment to enable the "fast debug" use for event
#define S_Debug			//Uncomment to enable the schedule debug
#define TDebug		1000

//Parameter definition
#define D_MinT		200	//Default minimal temperature 
#define D_MaxT		450     //Default max temperature (remember.... max 450!)
#define D_KP		2
#define D_KI		5
#define D_KD		7
#define D_TempGunApp	250
#define D_AirFlowApp	100
#define	D_AirFlowMin	40	//Default minimal air flow
#define	D_AirFlowMax	100	//Default minimal air flow
#define	D_Min_Pid	0
#define	D_Max_Pid	250
#define D_WeldCurv	1
#define D_Target1   	200	//Default target temp for weld curve
#define D_Time1		20	//Default target temp for weld curve
#define D_Target2   	250	//Default target temp for weld curve
#define D_Time2		20	//Default target temp for weld curve
#define	D_AutoOffTime	32000	//Default off timer 


//#define   LCD_Update	100	//UNUSED? LCD refresh interval
//#define   PID_Update	100

#define   PidTime	25	//Period 1 sec 60Hz		100	/Period 1S 50Hz
#define   ZeroCrossSec  100	//100 For 50Hz 120 for 60HZ 
#define   TStop		50	//Safe temp to disable GUN AirFlow

//#define   SumE_Min      -1000	//UNUSED? 
//#define   SumE_Max      1000	//UNUSED? 
#define   Pid_Out_Min	0	//Minimum limit for Pid calculation
#define   Pid_Out_Max	2000 ////1200 //Maximum limit for Pid calculation

//EEPROM data storage
#define   M_Temp	2
#define   M_Temp1	3
#define   M_AirFlow	4
#define   M_KP		5
#define   M_KI		6
#define   M_KD		7
#define   M_MinT	8
#define   M_MaxT	9
#define   M_MaxT1	10
#define   M_AutoOffTime	11
#define   M_AutoOffTime1	12
#define   M_WeldCurv	13
#define   M_Target1		14
#define   M_Target11	15
#define   M_Time1		16
#define   M_Target2		17
#define   M_Target21	18
#define   M_Time2		19



//I2cController vars definition
CtrlPanelLib contr(0x20);	// Connect via i2c, default address #0 (A0-A2 not jumpered)
#define POTDIVIDER		4	// Encoder tick divider for sensibilty regulation
#define CONTR_NOEVENT	0	// No event detected
#define CONTR_SCROLL	1	// Encoder movement detected -Z > read Pot value

uint8_t ControllerEvent = CONTR_NOEVENT; //Store encoder events
int TicPot = 0;           		//Used for cont of single step of rotary encoder
int PotDivider = POTDIVIDER;    	//Divider for TicPot for best regulation of sensitivity
int Pot , PotOld;
char ActEnc, OldEnc;   			//Diff between encoder positions
uint8_t PortA, IntA;
int ModVal, OldModVal;     				//Temporary var to store parameter during set
boolean InitPar = false;    		//Used by Menus
boolean EncClick, P1, P2, P3; //P4, P5;

//Pin definition
#define ZEROCINTPIN 2	//Interrupt pin used by zero crossing detector circuit DO NOT CHANGE
#define MCPINTPIN 	3	//Interrupt pin used by I2C controller (MCP23107)      DO NOT CHANGE
#define SO			5	//MAX6675 signal serial out aka MISO on SPI
#define CS			6	//MAX6675 signal Chip select
#define SCK			7	//MAX6675 signal clock
#define GATE		9 	//TRIAC gate
#define EMERG_RELAY 8	//Emergency and power relay
#define P_FAN_PWM	11  //Define pin D10 for pwm signal for gun
#define _STARTSTOP	12  //Pin used for activation of hot air production (also used for magnetic sensor on gun)
#define DEBUGLED	13  //Led used for debug purpose
#define HOLDER_SENS A3	//Tilt sensor for gun
#define FOOT_SWITCH A4	// Switch to anable the welding curve


//PWM and timers vars
#define PULSE	0x0F      //trigger pulse width (counts)
#define sbi(port,bit) (port)|=(1<<(bit))  //Fast toggle routine for pins

//Interrupts vars
byte MCPIntPin = MCPINTPIN; // Interrupts from the MCP will be handled by this PIN on Arduino
byte ArdMCPInterrupt = 1; // ... and this interrupt vector
byte ZeroCIntPin = ZEROCINTPIN; // Interrupts from zero crossing circuit
byte ArdZeroCInterrupt = 0; // ... and this interrupt vector

volatile boolean AwakenByMCPInterrupt   = false;
uint8_t PhaseCounter = 0; //increment at every phase zero crossing at 100 (=1 sec)  increment OpTime

//Timing vars
long	LcdUpd;           //Last time lcd was updated for real time Menu refresh es Home
long	RelayStartTime = 0;  //Relay time start: wait some time after start button press
int		AutoOffTime;    //Time for auto shutdown in seconds
int		OpTime = 0;   //operation Timer normally equal to millis(), used for temperature welding curve time calculation, displayed in home Menu
long	LastPIDTime = 0;  //Last time PID was calculated
long	TimeDeb;

//PID vars
char KI, KD, KP;    //Used by PID
bool DoPid = 0;   //Set to true if it's time to recalculate PID
long  SumE, Int_Res, Dev_Res, Err;//Used by PID
signed long Pid_Res;    //Used by PID
uint16_t TCNT_timer = 0;  //Calculate PID controller pulse width, used by interrupt

//Temp, Air, status vars
int LastActTemp = 0;
int ActTemp = 0;    //Actual gun air temp
int TempGunApp = 0; //Target temperature for PID temporary variable when weld cycle is not active
int TempGun = 0;    //Target temperature for PID, at work the air flow with this temp from gun
int AirFlowApp = 0; //Temporary variable for air flow when weld cycle is not active
int AirFlow = 0;
int MaxT = 0;
int MinT = 30;
boolean StartStop, PrevStartStop;
uint8_t WeldStatus;

//WeldCycle vars
//uint8_t CurveInd = 0;     //operation index for TempCurve array
boolean WeldCycle = 0;    //indicate if weld cycle temp is active
int WeldCurv, Target1, Time1, Target2, Time2;
long TimeStabl, TimeBuzz, TimeRamp, TimeTarg1, TimeTarg2;
bool TempInDelt, StartWlC, LiftUp;
int Delta;
#define Del_WlC	3	//Store ActTemp - TempGun on weld curve cycle
#define TBuzz	1000	//Buzzer time duration ms
#define TRamp	300

int X = 0;

uint8_t GG;

//Menu and display vars
#define Menu_HOME 0
#define Menu_TITLES 5
#define TimeLcd 1000
int Menu = Menu_HOME;
int MenuDec, MenuUnit;
int MenuOld = -1;
bool EditMode, EditPar, SaveConf, SavePar, SetMacEn;

/*
   First char convention for Menu voice handling:
   v=scroll -> next voice on right or left, click -> next voice down (default)
   h=goto home on click
   a=apply and go to home
*/
const char *MenuVoice[Menu_TITLES][10] =
{
  {"nFastSet", "vAirTemp", "vAirFlow", "hExit"},           //0,1,2..
  {"nParSet", "vKP", "vKI", "vKD", "vMinT", "vMaxT", "hExit"}, //10,11,12..
  {"nMaterials Presets", "aSn", "aheat shrink", "aLDPE", "aPP/Hard PVC/HDPE", "aABS/PC/Soft PVC", "hExit"}, //20..
  {"nWeldCurve", "aVeldCycle", "vTempCurve", "vTarget1", "vTime1", "vTarget2", "vTime2", "hExit"},                    //30..
  {"nFunct", "vAutoOff", "aDefault Setting", "hExit"},          //40..
};

/*

   TempCurve var

   |           _______________<Time2
   |         / ^Target2        \
   |  ______/<Time1             \
   | /   ^Target1
   |/
   L-----------------------------
   Set the themperature to a certain value.
   Calculate next event time and set it.

   const uint8_t TempCurve[]={target,time,target,time};
*/

/*
const uint8_t TempCurve[] = {   //target temp   //time to mantain temp
  150,      6,    //prehot
  155,      4,    //weld temp
  150,      5,    //weld temp
  180             //temperature after welding
};
*/

void HandleMCPInterrupt() {
  detachInterrupt(ArdMCPInterrupt);
  //A    |¯¯|__|¯¯|__|¯
  //B    ¯|__|¯¯|__|¯¯|__  +
  AwakenByMCPInterrupt = false;
  //uint8_t PortA = 0;
  PortA = contr.readRegister(MCP23017_GPIOA);
  IntA =  contr.readRegister(MCP23017_INTCAPA);
  ActEnc = ((PortA & 0b110) >> 1 );

  //Pot = 0;
  AwakenByMCPInterrupt = false;
  //PortA = contr.readRegister(MCP23017_GPIOA);

  ActEnc = ((PortA & 0b110) >> 1 );
  switch (ActEnc) {
    case 0: //00
      if (OldEnc == 2) TicPot++; //10
      if (OldEnc == 1) TicPot--; //01
      break;
    case 1: //01
      if (OldEnc == 0) TicPot++; //00
      if (OldEnc == 3 ) TicPot--; //11
      break;
    case 2: //10
      if (OldEnc == 3) TicPot++; //11
      if (OldEnc == 0 ) TicPot--; //00
      break;
    case 3: // 11
      if (OldEnc == 1) TicPot++; //01
      if (OldEnc == 2 ) TicPot--; //10
      break;
  }
  if (OldEnc != ActEnc) ControllerEvent = CONTR_SCROLL;
  OldEnc = ActEnc;
  if (TicPot >= PotDivider) {
    Pot++;
    TicPot = 0;
  } else if (TicPot <= -PotDivider)  {
    Pot--;
    TicPot = 0;
  }
  if (!bitRead(IntA, 0) && bitRead(PortA, 0)) EncClick = 1;	else EncClick = 0;
  if (!bitRead(IntA, 3) && bitRead(PortA, 3)) StartStop = 1; 					//P1 = 1;			else P1 = 0;
  if (!bitRead(IntA, 5) && bitRead(PortA, 5)) {StartStop = 0; StartWlC = 0;}	//P2 = 1;			else P2 = 0;
  if (!bitRead(IntA, 7) && bitRead(PortA, 7)) StartWlC = 1;						//else P3 = 0;
  if (StartWlC) {																//Disable panel navigation during the WLC cycle
	  Pot = 0;
	  EncClick = 0;
  }
  //cleanMCPInterrupts();
  //we set callback for the arduino INT handler.
  OpTime = 0;
  attachInterrupt(ArdMCPInterrupt, MCPintCallBack, FALLING);
}

void MCPintCallBack() {     //Low priority interrupt, the callback simply set a variable for interrupt handling fuctions in main loop.
  AwakenByMCPInterrupt = true;
}

void ZeroCCallBack() {      //High priority interrupt, only minimal operation and no time consumption routine
  detachInterrupt(ArdZeroCInterrupt);
  sbi(PINB, 5);             //Defined by macro on top for fast toggle pin D13 = DEBUGLED
  PhaseCounter++;
  if (PhaseCounter >= PidTime ) {
    PhaseCounter = 0;
    DoPid = 1;
  }
  OpTime--;
  /*
    TCNT_timer=65413; // 500us
    TCNT_timer=65288; // 1000us
    TCNT_timer=65038; // 2ms
    TCNT_timer=64538; // 4ms
    TCNT_timer=63538; // 8ms
  */
  TCNT1H = TCNT_timer >> 8;
  TCNT1L = TCNT_timer & 0x00FF;
  TIMSK1 |= (1 << TOIE1);
  //we set callback for the arduino INT handler.
  attachInterrupt(ArdZeroCInterrupt, ZeroCCallBack, RISING);
}

ISR(TIMER1_OVF_vect) { //timer1 overflow
  if (digitalRead(GATE) == 0) {
    TCNT1H = 0xFF;
    TCNT1L = 0xFF - PULSE;
    if (StartStop == 1 && Pid_Res > 10 && AirFlow > D_AirFlowMin && TempGun != 0) { //Check if StartStop var is active > welding active and some controls to vars
      digitalWrite(GATE, HIGH); //turn on TRIAC gate
    }
  } else {
    digitalWrite(GATE, LOW); //turn off TRIAC gate
    TIMSK1 &= ~(1 << TOIE1);
  }
}

#if defined S_Debug
void Debug() {
  GG = ~GG;
  contr.WriteLed(LED_4, GG);
  //Serial.println(Menu,DEC);
  //Serial.println(WeldCycle,DEC);
  //digitalWrite(LedV, !(digitalRead(LedV)));
  // Serial.println("Debug Programma");
  // Serial.print("MenuDec");
  // Serial.println(MenuDec);
  // Serial.print("MenuUnit");
  // Serial.println(MenuUnit );
  // Serial.print("Pot");
  // Serial.println(Pot);

  // Serial.print(KP, DEC);
  // Serial.print("\t");
  // Serial.println(KI, DEC);
  // Serial.print("\t");
  // Serial.println(KD, DEC);
}
#endif

void ModParMenu() {
  if (!InitPar) {           //First: set Modval with actual value of parameter
    switch (Menu) {
      case 1:   ModVal = TempGunApp;	break;
      case 2:   ModVal = AirFlowApp;	break;
      case 11:  ModVal = KP;			break;
      case 12:  ModVal = KI;			break;
      case 13:  ModVal = KD;			break;
      case 14:  ModVal = MinT;			break;
      case 15:  ModVal = MaxT;			break;
      case 32:  ModVal = WeldCurv;		break;
      case 33:  ModVal = Target1;		break;
      case 34:  ModVal = Time1;			break;
      case 35:  ModVal = Target2;		break;
      case 36:  ModVal = Time2;			break;	  
      case 41:  ModVal = AutoOffTime;	break;
    }
    InitPar = true;
    OldModVal = ModVal + 1;
    contr.setCursor(0, 1);
    contr.print(ModVal);
    //contr.setCursor(3, 1);
    contr.print(" ==>");
  }
  else {                   //Second: check if value is valid
    if (Menu == 41) ModVal = ModVal + (Pot * 100);
    else ModVal = ModVal + Pot;
    Pot = 0;
    switch (Menu) {
	case 1:   if (ModVal < 30) ModVal = 30;				if (ModVal  > D_MaxT) ModVal = D_MaxT;				break;
	case 2:   if (ModVal < D_AirFlowMin) ModVal = D_AirFlowMin; 	if (ModVal > D_AirFlowMax) ModVal = D_AirFlowMax;		break;
	case 11:  if (ModVal < D_Min_Pid)  ModVal = D_Min_Pid;		if (ModVal > D_Max_Pid) ModVal = D_Max_Pid;			break;
	case 12:  if (ModVal < D_Min_Pid)  ModVal = D_Min_Pid;		if (ModVal > D_Max_Pid) ModVal = D_Max_Pid;			break;
	case 13:  if (ModVal < D_Min_Pid)  ModVal = D_Min_Pid;		if (ModVal > D_Max_Pid) ModVal = D_Max_Pid;			break;
	case 14:  if (ModVal < 30) ModVal = 30 ;			if (ModVal  > D_MaxT) ModVal = D_MaxT;				break;
	case 15:  if (ModVal < 30) ModVal = 30 ;			if (ModVal  > D_MaxT) ModVal = D_MaxT;				break;
	case 32:  if (ModVal < 1) ModVal = 1;				if (ModVal  > 2) ModVal = 2;					break;
	case 33:  if (ModVal < 30) ModVal = 30;				if (ModVal  > D_MaxT) ModVal = D_MaxT;				break;
	case 34:  if (ModVal < 1) ModVal = 1;				if (ModVal  > 250) ModVal = 250;				break;
	case 35:  if (ModVal < 30) ModVal = 30;				if (ModVal  > D_MaxT) ModVal = D_MaxT;				break;
	case 36:  if (ModVal < 1) ModVal = 1;				if (ModVal  > 250) ModVal = 250;				break;
	case 41:  if (ModVal < -32000) ModVal = -32000;			if (ModVal  > -100) ModVal = -100;				break;
    }
  }
  if (OldModVal != ModVal) {
    contr.setCursor(7, 1);
    contr.print("   ");
    contr.setCursor(8, 1);
    contr.print(ModVal);
    OldModVal = ModVal;
  }
}

void SaveParMenu() {
  switch (Menu) {   //Third: save valid modified parameter on eeprom
    case 1:  TempGunApp = ModVal;  EEPROM.write(M_Temp, TempGunApp);     EEPROM.write(M_Temp1, (TempGunApp >> 8)); break;          //Save long value  to two eeprom memory bytes.
    case 2:  AirFlowApp = AirFlow = ModVal;	EEPROM.write(M_AirFlow, AirFlowApp);		break;
    case 11:  KP  = ModVal;		EEPROM.write(M_KP, KP);					break;
    case 12:  KI  = ModVal;		EEPROM.write(M_KI, KI);					break;
    case 13:  KD  = ModVal;		EEPROM.write(M_KD, KD);					break;
    case 14:  MinT  = ModVal;		EEPROM.write(M_MinT, MinT);				break;
    case 15:  MaxT  = ModVal;		EEPROM.write(M_MaxT, MaxT); EEPROM.write(M_MaxT1, (MaxT >> 8));		    break;
    case 32:  WeldCurv = ModVal;  EEPROM.write(M_WeldCurv  , WeldCurv);				break;
    case 33:  Target1 = ModVal;  EEPROM.write(M_Target1  , Target1);     EEPROM.write(M_Target11 , (Target1 >> 8)); break;
    case 34:  Time1  = ModVal;		EEPROM.write(M_Time1, Time1);				break;
    case 35:  Target2 = ModVal;  EEPROM.write(M_Target2  , Target2);     EEPROM.write(M_Target21 , (Target2 >> 8)); break;
    case 36:  Time2  = ModVal;		EEPROM.write(M_Time2, Time2);				break;
    case 41:  AutoOffTime = ModVal;	EEPROM.write(M_AutoOffTime, AutoOffTime); EEPROM.write(M_AutoOffTime1, (AutoOffTime >> 8)); AutoOffTime = 1 - AutoOffTime; break; //Save long value  to two eeprom memory bytes.
  }
  InitPar = false;
}

void SetMac() {
  switch (Menu) {
    case 21:  TempGunApp = 300; AirFlowApp = 80;	break;         //Example for predefined temp and air flow for Sn
    case 22:  TempGunApp = 120; AirFlowApp = 100;	break;        //Example for predefined temp and air flow for a specific function heat shrink tubing
    case 23:  TempGunApp = 270; AirFlowApp = 100;	break;        //Example for predefined temp and air flow for a specific function weld LDPE
    case 24:  TempGunApp = 300; AirFlowApp = 100; 	break;        //Example for predefined temp and air flow for a specific function weld PP,Hard PVC, Hard PE
    case 25:  TempGunApp = 350; AirFlowApp = 100; 	break;        //Example for predefined temp and air flow for a specific function weld ABS, PC, Soft PVC
    case 31:  WeldCycle = ~ WeldCycle;  		break;        //Set WeldCycle var now at every loop weldCurve routine is checked to the end of temperature weld cycle
    case 42:  DefVal(); 				break;
  }
  InitPar = false;
}
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
void loop() {
  //  if (checkerror()==1) {                  //  Error and emergengy handling function
  //    TempGun=0;
  //    AirFlow=100;
  //    digitalWrite(EMERG_RELAY,LOW);    //Disable power to gun
  //   #if defined F_Debug
  //   Serial.println("Shutdown after error!");
  //   #endif
  //   exit(0);
  //  }
  if (DoPid) {          //Check if PID recalc is needed(recalc after 1 second)
    PID();
    DoPid = 0;
#if defined SerialPlot
    Serial.print(ActTemp);
    Serial.print("\t");
    Serial.print(TempGun);
    //Serial.print("\t");
    // Serial.print(Pid_Res);
    // Serial.print("\t");
    // Serial.print(Err);
    // Serial.print("\t");
    // Serial.print(Int_Res);
    // Serial.print("\t");
    // Serial.print(Dev_Res);
    //Serial.println("\t");
    //Serial.print( Delta);
    Serial.println("\t");
#endif
  }
  startstop();
  if (AwakenByMCPInterrupt) {
    HandleMCPInterrupt();   //Handle low priority interrupt (user interface: encoder, switch) if fired
  }
  OCR2A = map(AirFlow, 0, 100, 0, 255); //Adapt percent value to 0-255 scale for timer and apply to OCR2A register for pwm generation.
#if defined S_Debug
  if (millis() > TimeDeb) {
    TimeDeb = (millis() + TDebug);
    Debug();
  }
#endif
  if (EditMode && (Menu != MenuOld)) {
    if (MenuOld != 100) contr.clear();
    contr.setCursor(0, 0);
    MenuDec = Menu / 10;
    MenuUnit = Menu % 10;
    if (EditPar && !SavePar) contr.print("Mod ");
    if (SaveConf) contr.print("Save ");
    contr.print(&MenuVoice[MenuDec][MenuUnit][1]);  //Start printing lcd from second char to hide first Menu control char
    MenuOld = Menu;
  }
  else if ( !EditMode && millis() > LcdUpd ) {    //Home Menu special handler for live update var every second
    contr.clear();
    contr.print("T:");
    contr.print(ActTemp);
    contr.print("/");
    contr.print(TempGun);
    contr.setCursor(10, 0);
    contr.print("A:");
    contr.print(AirFlow);
    contr.print("%");
    contr.setCursor(12, 1);
    if (StartStop == 1) {
	if (WeldCycle) contr.print("WelC");
	else contr.print("Weld");
    }
    else {
      contr.print("Stop");
    }
    contr.setCursor(0, 1);
    if (WeldCycle > 0) {
      contr.print("o:");
      contr.print(OpTime/ZeroCrossSec);
    }
    else {
      contr.print("t:");
      contr.print(OpTime/ZeroCrossSec);
    }
    LcdUpd = millis() + TimeLcd;
  }

  if (EncClick && MenuVoice[MenuDec][MenuUnit][0] == 'n') { //On MenuVoice=Exit goto Menu tilet`
    if (MenuDec < Menu_TITLES - 1) {              //Skip next level if not maximum level
      Menu = Menu + 10;
      if (!EditMode) {
        EditMode = 1;
        Menu = Menu_HOME;
        MenuOld = 1;
        PotDivider = 4;
      }
    }
    else  {
      Menu = Menu_HOME;       //if maximum level return to home
      EditMode = 0;
      MenuDec = MenuUnit = 0;
    }
    EncClick = 0;
  }

  if (ControllerEvent == CONTR_SCROLL && EditMode && !EditPar && !SaveConf ) {
    if (MenuVoice[MenuDec][MenuUnit][0] != 'h' && Pot == +1) { //scorre solo fino all'ultima voce del Menu
      Menu = Pot + Menu;
    }
    else if (MenuUnit > 0 && Pot == -1) { //torna indietro ruotando la rotella solo però fino alla  prima voce
      Menu = Pot + Menu;
    }
    Pot = 0;
    ControllerEvent = CONTR_NOEVENT;
  };

  if (EncClick && !EditPar && !SaveConf  && MenuVoice[MenuDec][MenuUnit][0] == 'v') { //On MenuVoice=Exit goto Menu tilet`
    EditPar = 1;
    EncClick = 0;
#ifdef F_Debug
    Serial.print("Edit");
#endif
    MenuOld = 100;
  }

  if (EncClick && !SaveConf && MenuVoice[MenuDec][MenuUnit][0] == 'v') { //On MenuVoice=Exit goto Menu tilet`
    //SavePar = 1;
    SaveConf = 1;
    EditPar = 0;
    EncClick = 0;
    PotDivider = 3;
    Pot = 2;
    PotOld = 0;
#ifdef F_Debug
    Serial.print("Save");
#endif
    MenuOld = 100;
  }

  if ( EditPar) {
    ModParMenu();
    PotDivider = 1;
  }

  if (SaveConf) {
    if (Pot != PotOld) {
      contr.setCursor(13, 1);
      if (Pot > 1) {
        contr.print("YES");
        Pot = 2;
      }
      if (Pot < -1) {
        contr.print("NO ");
        Pot = -2;
      }
      PotOld = Pot;
    }

    if (EncClick && !SetMacEn && Pot > 1) {
      SaveParMenu();
      //Menu = MenuDec = MenuUnit = 0;

      //EditMode = EditPar = SaveConf = 0;
      EditPar = SavePar = 0;
      EncClick = 0;
      SaveConf = 0;
      InitPar = 0;
      MenuOld = 0;
      contr.setCursor(0, 1);
      for (char i = 0; i <= 16; i++) contr.print(" ");
      contr.buzz(200, 1500);
    }

    if (EncClick && SetMacEn && Pot > 1) {
      SetMac();
      Menu = MenuDec = MenuUnit = 0;
      SetMacEn = 0;
      SaveConf = 0;
      EncClick = 0;
      EditMode = 0;
      contr.buzz(200, 1500);
    }

    if (EncClick && Pot < -1) {
      //SaveParMenu();
      //Menu = MenuDec = MenuUnit = 0;
      EditPar = SavePar = 0;
      EncClick = 0;
      SaveConf = 0;
      InitPar = 0;
      MenuOld = 0;
      contr.setCursor(0, 1);
      for (char i = 0; i <= 16; i++) contr.print(" ");
      contr.buzz(500, 200);
    }
  }

  if (EncClick && !SaveConf && MenuVoice[MenuDec][MenuUnit][0] == 'a') { //On MenuVoice=Exit goto Menu tilet`
    contr.setCursor(0, 1);
    contr.print("Are You Sure");
    SaveConf = 1;
    EncClick = 0;
    PotDivider = 3;
    Pot = 2;
    PotOld = 0;
    SetMacEn = 1;
  }
  if (EncClick && !SaveConf && MenuVoice[MenuDec][MenuUnit][0] == 'h') { //On MenuVoice=Exit goto Menu tilet`
    Menu = MenuDec = MenuUnit = 0;
    EditMode = EditPar = SaveConf = 0;
    EncClick = 0;
  }


  if (WeldCycle > 0) { //Check if weld temperature cycle is active and then invoke it
    weldCurve();
  }

  if (OpTime < AutoOffTime ) {  //Shutdown if inactive, other settings are required.....
    TempGun = 0;
    TempGunApp = 0;
    contr.setCursor(0, 1);
    contr.print("Auto Power OFF");
    AirFlow = 100;
    AirFlowApp = 100;
    //Serial.println("Auto Power OFF");
    if (ActTemp <= TStop) {
      AirFlow = 0;  //when air on gun is lower than TStop temp cut off pwm on fan
      OCR2A = 0;
      Serial.println("Fan stop");
      delay(500);
      exit(0);
    }
  }
}

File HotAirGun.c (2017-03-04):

/******************************************************************************\
* Hot Air Welder  Programs control											   *
* Mcu  Pic 16F876 to 4 Mhz,  pic run the PID control to control the air        *
* temperature to the target also the PWM to control the fan speed / ari flow   *
\******************************************************************************/
// Lcd pinout settings
sbit LCD_RS at RA0_bit;
sbit LCD_EN at RA1_bit;
sbit LCD_D7 at RA5_bit;
sbit LCD_D6 at RA4_bit;
sbit LCD_D5 at RA3_bit;
sbit LCD_D4 at RA2_bit;

// Pin direction
sbit LCD_RS_Direction at TRISA0_bit;
sbit LCD_EN_Direction at TRISA1_bit;
sbit LCD_D7_Direction at TRISA5_bit;
sbit LCD_D6_Direction at TRISA4_bit;
sbit LCD_D5_Direction at TRISA3_bit;
sbit LCD_D4_Direction at TRISA2_bit;

#define FaseDetect  PORTB.F0   // Interrupt RB0 Detect the 0 point on 220V
#define Heater      PORTB.F1   // Output for the SCR
#define Start       PORTB.F6   // Start Button
#define Stop        PORTB.F2   // Stop Button
#define Fase_A      PORTB.F4   // Warming!!!! Encoder signal Pull-Up
#define Fase_B      PORTB.F5   // Warming!!!! Encoder signal Pull-Up
#define SwitchEnc   PORTB.F3
#define GunStand    PORTB.F7

#define CS          PORTC.F0   // For Max6675
#define PWMFan      PORTC.F1   // PWM2
#define CSK         PORTC.F2   // For Max6675
#define SO          PORTC.F3   // For Max6675
//#define PORTC.F
#define LedR        PORTC.F5   //System Run
#define LedV        PORTC.F6   // Interrupt Access
//#define         PORTC.F7

//Bit Programma
#define Edit       VarBool.F0
#define MemSw      VarBool.F1
#define StartCicle VarBool.F2
#define DoPid      VarBool.F3
#define Tc_Allarm  VarBool.F4
#define Time_Stop  VarBool.F5
//#define VarBool.F6
//#define VarBool.F7


// Costanti Programma
#define Eprom_Add 0
#define Min_Row   10
#define Max_Row   11
#define Min_Temp  100
#define Max_Temp  400
#define TempStop  40
#define Min_Flow  1
#define Max_Flow  100
#define PotScale  1
#define PidTime   100      //Period 1 sec
#define TStop     25
#define Kp           1
#define Ki           2
#define Kd           6
#define SumE_Min     -1200
#define SumE_Max     1200
#define PidOutMin    0
#define PidOutMax    1200


//Pid Var
signed int  SumE, Int_Res, Dev_Res, Err, Err1;
signed long Pid_Res;
// Program Var
char VarBool;
unsigned int PulseTime;
unsigned char Stop_Loop;
char PidCount;
//Menu & Parameter
signed char Pot;
char Act_PortB, Old_PortB;		//Dig Pot
unsigned char LcdRow,LcdRowOld,Loop;
unsigned int TempGun,ActTemp; 	
unsigned char AirFlow;			



//Lcd Mess
const char Logo[]=   "Msystem";
const char Logo1[]=  "HotAirGun V1.0";
const char StatMen[]="Act Temp  C";
const char Menu1[]=  "TempGun   C";
const char Menu2[]=  "AirFlow   %";
const char All[]=    "ThermoC Error!!";

//void PID ();
void Init();
void Lcd_3Dig(char Row,char Col,int Dat);
void Lcd_Fl_Str(char Row, char Col, unsigned Text);
void TC_Read();
signed int TempC();
void PID();


void main(){
 Init();
 VarBool=0;
 LcdRow=Min_Row;
 LcdRowOld=Max_Row;
 Stop_Loop=0;
 Lcd_Fl_Str(1,5,Logo);
 Lcd_Fl_Str(2,1,Logo1);
 Delay_ms(1000);
 Lcd_Cmd(_LCD_CLEAR);
 Lcd_Fl_Str(1,2,StatMen);


 //Read Data Fron EEprom
 //TempGun=80;//EEprom_read(Eprom_Add);
 TempGun=EEprom_read(Eprom_Add);
 TempGun=(TempGun<<8)+EEprom_read(Eprom_Add+1);
 AirFlow=EEprom_read(Eprom_Add+2);


 while (1){


 if(DoPid){
   DoPid=0;
   //LedV=~LedV;
   if(Stop_Loop>=1) Stop_Loop-=1;     //CoutDown Stop 1Sec
   ActTemp=TempC();
   if(ActTemp==-1) Tc_Allarm=1;
     else ActTemp=((ActTemp*8)/10);
   Lcd_3Dig(1,13,ActTemp);
   if(StartCicle)PID();
   //if(StartCicle==0){ Err=Err1=SumE=0;}
   //Lcd_3Dig(2,3,Pid_Res);
   }
 //Digital Potentiometer
   Act_PortB = PORTB& 0X30;
   if (Act_PortB!=Old_PortB){
    switch(Old_PortB)
     {
    case 0:     //0b0000 0000
      if((Act_PortB.F4==1)&&(Act_PortB.F5==0)) Pot-=1;
      if((Act_PortB.F4==0)&&(Act_PortB.F5==1)) Pot+=1;
    break;
    /*case 16:    //0b0001 0000
      if((Act_PortB.F4==1)&&(Act_PortB.F5==1)) Pot-=1;
      if((Act_PortB.F4==0)&&(Act_PortB.F5==0)) Pot+=1;
    break;*/
    case 48:    //0b0011 0000
      if((Act_PortB.F4==0)&&(Act_PortB.F5==1)) Pot-=1;
      if((Act_PortB.F4==1)&&(Act_PortB.F5==0)) Pot+=1;
    break;
    /*case 32:    //0b0010 0000
      if((Act_PortB.F4==0)&&(Act_PortB.F5==0)) Pot-=1;
      if((Act_PortB.F4==1)&&(Act_PortB.F5==1)) Pot+=1;
    break;*/
   }
    Old_PortB= Act_PortB;
  }

   if((SwitchEnc==0)&&(Edit==0)&&(MemSw==0))  {
    Edit=1;
    MemSw=1;
   }
   if((SwitchEnc==0)&&(Edit)&&(MemSw==0))  {
    Edit=0;
    MemSw=1;
   switch(LcdRow)
   {
    case 0x0A: EEprom_write(Eprom_Add+1,TempGun+1);EEprom_write(Eprom_Add,(TempGun>>8));break;
    case 0x0B: EEprom_write(Eprom_Add+2,AirFlow);break;
   } //End Switch
  }

  if(SwitchEnc) MemSw=0;

  if (Edit==0){     //Change row
    Loop+=Pot;
    if((Loop>2)||(Loop<-2)) {
       LcdRow+=Pot;
       Loop=0;
      }
    Pot=0;
  }
  if (LcdRow<Min_Row)  LcdRow=Min_Row;
  if (LcdRow>Max_Row)  LcdRow=Max_Row;


  // Dynamic pages

   if(LcdRow!=LcdRowOld){
     switch(LcdRow)
     {
      case 0x0A:
        Lcd_Fl_Str(2,2,Menu1);
        Lcd_3Dig(2,13,TempGun);
      break;
      case 0x0B:
        Lcd_Fl_Str(2,2,Menu2);
        Lcd_3Dig(2,13,AirFlow);
      break;

    } //End Switch
    LcdRowOld=LcdRow;
  }  //End Schermate Dinamiche

  if (Tc_Allarm) Lcd_Fl_Str(2,1,All);    //Termocouple Allarm

  if ((Edit)&&(Pot!=0))    //Variables
  {
   switch(LcdRow){
      case 0x0A:
         TempGun+=Pot;
         Pot=0;
         if (TempGun<Min_Temp) TempGun=Min_Temp;
         if (TempGun>Max_Temp) TempGun=Max_Temp;
         Lcd_3Dig(2,13,TempGun);
      break;
      case 0x0B:
         AirFlow+=Pot;
         Pot=0;
         if (AirFlow<Min_Flow) AirFlow=Min_Flow;
         if (AirFlow>Max_Flow) AirFlow=Max_Flow;
         Lcd_3Dig(2,13,AirFlow);
      break;
   }
  }  

  // Cicle Start Stop
  if (Start==0) {
   PWM2_Start();
   PWM2_Set_Duty(255);
   Delay_ms(2000);
   StartCicle=1;
  }
 if ((Stop==0)||(Tc_Allarm)) {
   StartCicle=0;

   if (Time_Stop==0){
    Time_Stop=1;
    Stop_Loop=TStop;
   }
  }
  LedR=StartCicle;
  if(StartCicle)PWM2_Set_Duty(154+AirFlow);
  if((StartCicle==0)&&(Time_Stop==1)){
   PWM2_Set_Duty(254);
   if (ActTemp<=TempStop){
     PWM2_Stop();
     PWMFan=0;
     Time_Stop=0;
     }
   }

 }    // Emd While
}     // End Main





void interrupt (){

 //INTCON.GIE=0;
 if(INTCON.INTF){
  INTCON.INTF=0;
  Heater=0;
  PidCount+=1;
  if(PidCount>=PidTime){
     DoPid=1;

     PidCount=0;
     }
 // LedV=~LedV;
  T1CON.B0=0;
  TMR1L=(PulseTime);          //It's calculated by subtracting the overflow
  TMR1H=(PulseTime>>8);
  T1CON.B0=1;
 }// //End Interrupt RB0

  if(PIR1.B0){   // Tmr1 Interrupt to generate the pulse fase
   PIR1.TMR1IF=0;
   LedV=~LedV;
   if (StartCicle) Heater=1;
   //Heater=~Heater;
   //Heater=1;
   Delay_us(10);
   Heater=0;
  }
 INTCON      =0b11010000;
 }//End Interrupt routine
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

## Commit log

2017-03-05 Rename Piedini scheda.stl to 3D/Piedini scheda.stl
    [Piedini scheda.stl]
2017-03-05 Rename colonna 130.stl to 3D/colonna 130.stl
    [colonna 130.stl]
2017-03-05 Rename colonna 106.stl to 3D/colonna 106.stl
    [colonna 106.stl]
2017-03-05 Rename Sostegno Induttanza.stl to 3D/Sostegno Induttanza.stl
    [Sostegno Induttanza.stl]
2017-03-05 Rename Staffa alim.stl to 3D/PWSuplSupp.stl
    [PWSuplSupp.stl]
2017-03-05 Rename Piedini scheda.stl to BoardFix.stl
    [BoardFix.stl]
2017-03-05 Rename Sostegno Induttanza.stl to CoilSupport.stl
    [CoilSupport.stl]
2017-03-05 Rename colonna 106.stl to Coulom106.stl
    [Coulom106.stl]
2017-03-05 Rename colonna 130.stl to Coulom130.stl
    [Coulom130.stl]
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2017-03-31 Import schema e conversione manuale in formato kicad, i componenti non disponibili nelle librerie di default di kicad sono stati sostituiti con rettangoli tratteggiati in attesa di conferma
    [HotAriGun-SchDoc.sch]
2017-03-31 Rename files per uniformare a nome progetto
    [HotAirGun.sch]
2017-03-31 Aggiornamento componenti e inclusione nell'archivio del cache libreria
    [HotAirGun.sch]
2017-03-31 Modifica dimensione pagina foglio schema elettrico settato A4 per migliorare la stampa, aggiornamento informazioni sul foglio
    [HotAirGun.sch]
2017-04-01 Modifica README.md, pubblicazione schemi
    [HotAirGun.sch]
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2017-04-10 Schema aggiornato con arduino nano
    [HotAirGun.sch]
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2017-09-13 Update schematics plot
    Align plots to kicad schematics for preview and print without kicad
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2017-09-14 potDivider var for scroll sensibility regulation
    Add of potDivider variable make a regulation of sensibility of encoder.
    Functional in case of high speed encoder or encoder with low precison.
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2017-09-17 New function TempCurve
    Implement temperature cycle to follow datasheet temperature cycle for welding of specific components
2017-09-18 AutoOFFTime setting in menu and some var name repl
    Adding function in menu for AutoOffTime adjst with encoder and save to eeprom (2 bytes).
    Some var name adjust with wrong name after text replace.
    [HotAirGun.ino]
2017-09-20 INT0 handler use zero cross signal for PID base
    handler for INT0 interrupt, high priority interrupt, tested with logic analyzer
    react in 3.2usec with toglle of pin
    Hardware TIP resistor pullup is required for D2 and D3 even interrupt is not handled correctly
    some typo correction and comment corrections
    [HotAirGun.ino]
2017-09-20 Code indent and typo correction
    [HotAirGun.ino]
2017-09-21 Addi comments and typo corrections
    [HotAirGun.ino]
2017-09-21 Pwm signl on pin D10 for fan control
    Add PWM control on pin D10 for fan contol, the frequncy of pwm have to be checked if corrected.
    Implent of pwn off when auto off is active.
    [HotAirGun.ino]
2017-09-22 opTime decrement in interrupt phase routine
    assure opTime decrement in every condition.
    added also a exit(0) when autoshutdown occur
2017-09-22 Change handling of MCP23017 interrupts
    They are cheched every loop and other functions are handled if buttons and encoder events
    are already handled.
2017-09-22 Replace wrong D_AutoOffTime var with AutoOffTime
    Correction for auto shutdown time calculation.
    Some Serial print and debug messages.
    [HotAirGun.ino]
2017-09-25 Schematic update pullup for int pin
    [HotAirGun.sch]
2017-09-25 Multiple sheet schematic
    Change schematic to multiple sheet format
    [AC_control.sch, I2cController.sch, Microcontroller.sch]
2017-09-25 Add Gun image to general schematic
    [HotAirGun.sch]
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2017-09-27 Introduction of function PID from V1 branch
    Reuse of PID function from V1 branch with variable definitions
2017-10-01 Change interrupt handling priority
    Assure continuous handling of pid recalc in case of continuous int1 events
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2017-10-03 Use timer2 for air flow pwm
    timer 2 is 8 bit counter based, timer1 is more accurate and in future used for triac
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2017-10-10 Config TIMER1 and interrupt for TRIAC driving
    Reconfiguration of TIMR1 for overflow interrupt and pulse generation for triac.
    At zero crossing event timer duration is recalculated
    TCNT_timer=63060+Pid_Res;
    at the first overflow new value is set for low duration pulse
    TCNT1H = 0xFF;
    TCNT1L = 0xFF - PULSE;
    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
2017-10-19 MAXX6675 corrections and error for chip unconneted
    After installation of real chip, code require correction
    Add of chip disconnetion handling checking D1 bit. See datasheet.
    [HotAirGun.ino]
2017-10-24 Schematic update
    [AC_control.sch, HotAirGun.sch, I2cController.sch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]
2017-11-01 Modified the Kicad schematic adding the reset to I2c controller
    [AC_control.sch, HotAirGun.sch, I2cController.sch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]
2017-11-01 added step-down circuit
    [AC_control.sch, HotAirGun.sch, I2cController.sch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]
2017-11-05 Emergency and error function handler
    Some controls for thermocuople and zero cross circuit error detection and
    shutdown.
    Assigned arbitrary pin to emergency relay to be confirmed.
    [HotAirGun.ino]
2017-11-06 Introducing var TempGunApp and AirFlowApp
    New vars for start and stop cycle used when weld cycle is not active
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2017-11-09 Start and stop function revisited
    New function for start and stop button.
    Start sequence:
    - Fan start
    - Wait 2 sec
    - Relay On
    - Start Triac activation
    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
2017-11-10 Startstop revision
    In previous commit STARTSTOP was associated to phisical pin status.
    Now if STARTSTOP macro is defined phisical pin is also usable for guns with magnetic sensor.
    Else if STARTSTOP is undef 2 buttons of cross keyboard up and down are used as start and stop buttons.
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2017-11-13 Update the schematic with the safety relays for 220V. Microcontroller page now is connect with the grid.
    [AC_control.sch, HotAirGun.sch, I2cController.sch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]
2017-11-16 Replaced version before merge
    [HotAirGun.ino]
2017-11-16 Reduce some pic resolution. Update PDF schematic.
    [AC_control.sch, HotAirGun.sch, I2cController.sch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]
2018-12-31 New PCB version with smd component Added plot folder with gerber file
    [AC_control.sch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]
2019-02-19 Update with new PCB version
    Kicad schematic and pcb layout correction on Mosfet and Triac footprint.
    [AC_control.sch, HotAirGun.kicad_pcb, I2cController.sch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]
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2019-03-21 Kicad project mistake correction
    [AC_control.sch, HotAirGun.kicad_pcb, HotAirGun.sch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]
2019-05-07 New STL file for 3D printer housing
    [Back.stl, BoardFix.stl, Button.stl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]
2019-05-08 Fixing support modification
    [Front.stl]
2019-05-18 3D model update
    [P-S Fixing.stl, Pcb Fixing.stl, Pot.stl]
2019-05-24 Added C5 bypass capacitor
    [HotAirGun.kicad_pcb, I2cController.sch]
2019-05-24 Added C6 bypass capacitor
    [HotAirGun.kicad_pcb, I2cController.sch, Microcontroller.sch]
2019-06-17 Frame modification
    Some adjustment to the rear part height and column 123
    Added some note on KiCad project
    [Coloumn 123.stl, HotAirGun.kicad_pcb, Rear.stl]
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2019-07-04 Convert fixed temp to Tstop var
    [HotAirGun.ino]
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
